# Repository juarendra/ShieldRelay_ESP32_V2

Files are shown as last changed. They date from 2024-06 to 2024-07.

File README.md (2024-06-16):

# ShieldRelay_ESP32
Multiple Relay with ESP32 shield. In board there are 5 Relay and 3 type of Relay, first is 30A Relay Coil, second is 10 A Relay Coil and third is SSR 2A. And there are full extend header of Microcontroller. the power using Stepdown LM2596 with output 5V 3A and Input 5-30VDC. 

## Spesification ShieldRelay_ESP32
- Input Power 5-30VDC and stepdown to 5VDC
- PTC Fuse
- INPUT HEADER
- VCC HEADER
- VCC Selector 3v3 or 5V
- ESP32 WROON on BOARD
- Pin Header GPIO with Servo Formated
- 1 x 30A Relay Coil
- 2 x 10A Relay Coil
- 2 x 2A SSR

# Privew Hardware BASE RPI
<p align="center">
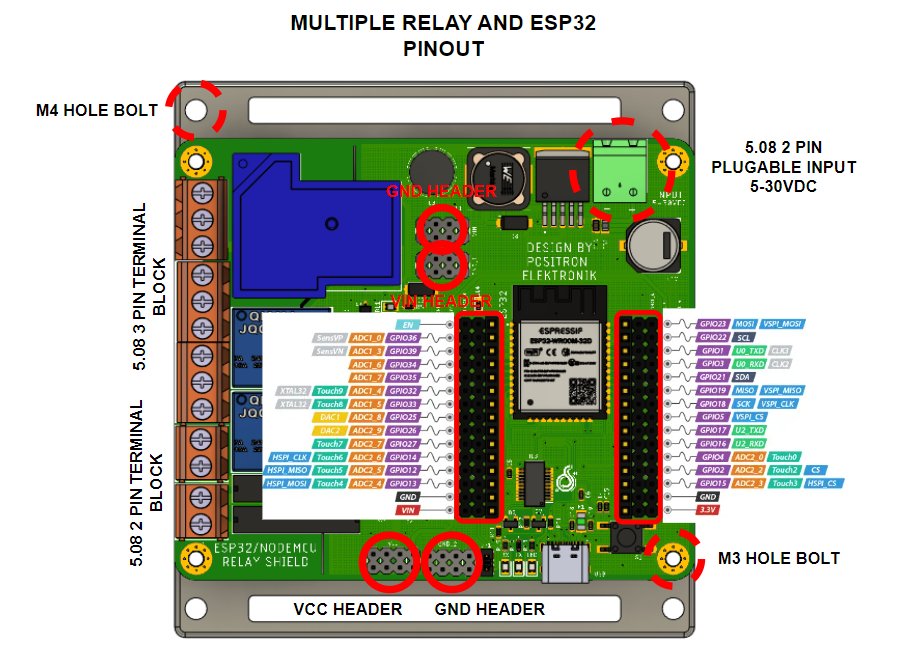
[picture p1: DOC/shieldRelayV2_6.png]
  
</p>

# Privew Hardware BASE RPI
<p align="center">
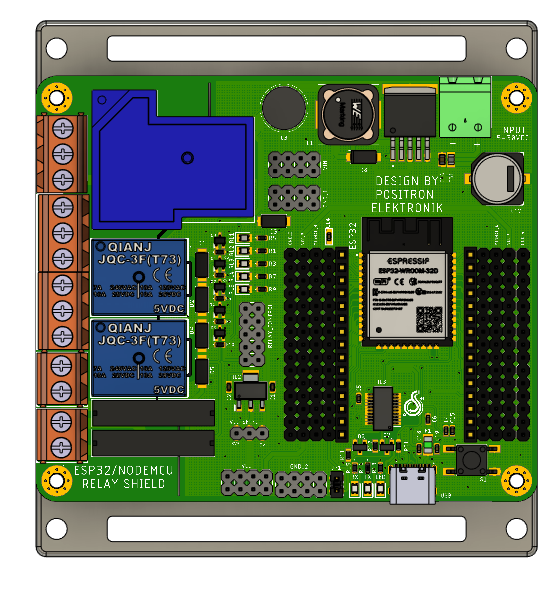
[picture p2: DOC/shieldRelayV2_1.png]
  
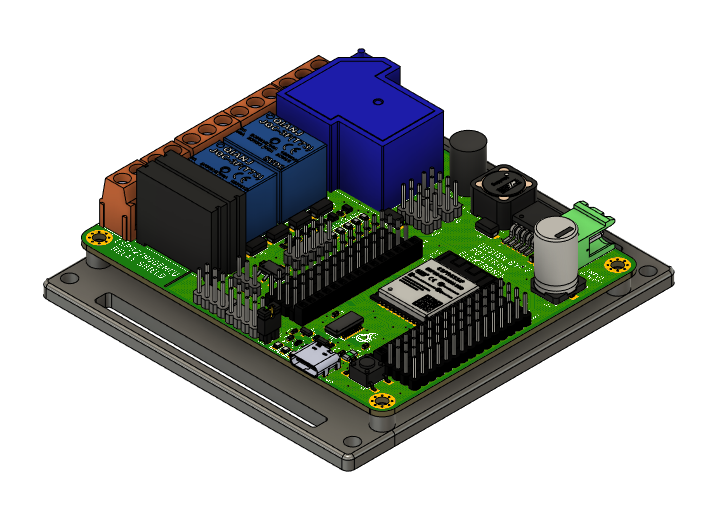
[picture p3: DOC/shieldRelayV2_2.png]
  
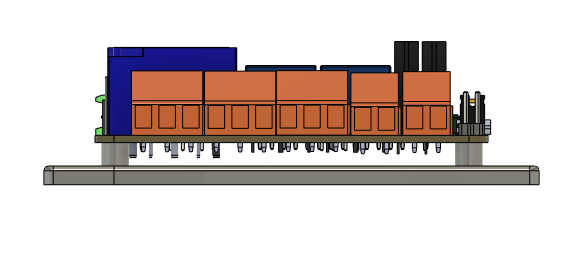
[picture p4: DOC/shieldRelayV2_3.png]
  
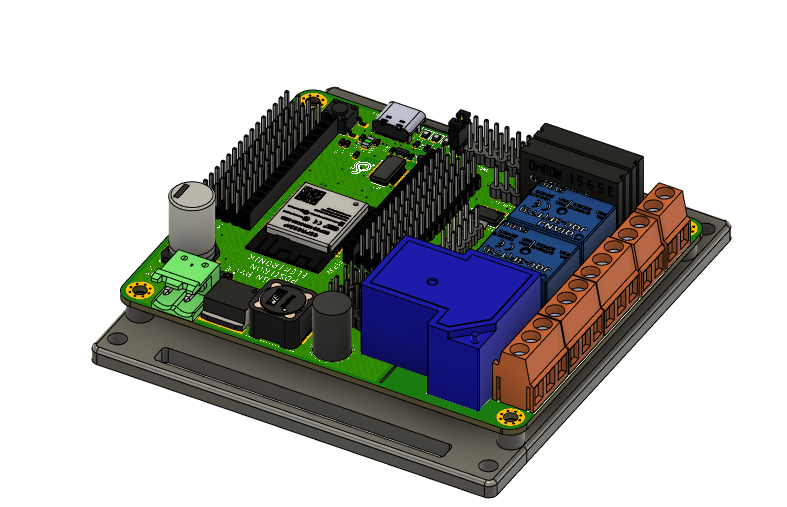
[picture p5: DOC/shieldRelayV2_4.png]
  
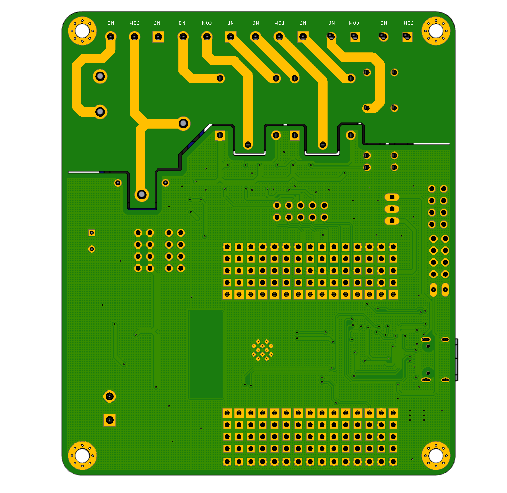
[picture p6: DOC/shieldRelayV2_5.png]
  
</p>

# Documentation 
- [Dimension](https://github.com/juarendra/ShieldRelay_ESP32_V2/blob/main/HARDWARE/dimension_shield_esp32_v2.pdf)
- [BOM](https://github.com/juarendra/ShieldRelay_ESP32_V2/blob/main/DOC/shieldRelayV2.csv)

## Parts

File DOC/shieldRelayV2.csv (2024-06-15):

Qty | Value | Device | Package | Parts | Description | ARROW_PART_NUMBER | ARROW_PRICE-STOCK | AVAILABILITY | CHECK_PRICES | DESCRIPTION | DIGIKEY_PARTNUMBER | DIGIKEY_PRICE-STOCK | ESP32-DEVKITV1 | HEIGHT | MANUFACTURER_NAME | MANUFACTURER_PART_NUMBER | MF | MOUSER_PART_NUMBER | MOUSER_PRICE-STOCK | MP | PACKAGE | POPULARITY | PRICE | PURCHASE-URL | SNAPEDA_LINK | VALUE
1 |  | JP1E | JP1 | JP1 | JUMPER |  |  |  |  |  |  |  |  |  |  |  |  |  |  |  |  | 61
8 |  | PINHD-1X15 | 1X15 | GND_3, GND_4, JP11, JP12, SIGNAL_3, SIGNAL_4, VCC_3, VCC_4 | PIN HEADER |  |  |  |  |  |  |  |  |  |  |  |  |  |  |  |  | 4
1 |  | PINHD-1X3 | 1X03 | VCC_SELECT | PIN HEADER |  |  |  |  |  |  |  |  |  |  |  |  |  |  |  |  | 92
4 |  | PINHD-2X4 | 2X04 | GND_1, GND_2, VCC, VIN | PIN HEADER |  |  |  |  |  |  |  |  |  |  |  |  |  |  |  |  | 47
1 |  | PINHD-2X5 | 2X05 | RELAY_CONTROL | PIN HEADER |  |  |  |  |  |  |  |  |  |  |  |  |  |  |  |  | 35
2 | 0.1uf | KGM15BR71E104KT | CAPC1608X95N | C1, C2 | 0603 25 V X7R 100nF +/-10% |  |  |  |  | 0603 25 V X7R 100nF +/-10% |  |  |  | 0.95mm | Kyocera AVX | KGM15BR71E104KT |  | 581-KGM15BR71E104KT | https://www.mouser.co.uk/ProductDetail/KYOCERA-AVX/KGM15BR71E104KT?qs=Jm2GQyTW%2FbiCo%2Fby4Q068Q%3D%3D
1 | 0ZCJ0010FF2E | 0ZCJ0010FF2E | FUSC3216X75N | F1 | Resettable Fuses - PPTC Fuse |  |  |  |  | Resettable Fuses - PPTC Fuse |  |  |  | 0.75mm | BelFuse | 0ZCJ0010FF2E |  | 530-0ZCJ0010FF2E | https://www.mouser.co.uk/ProductDetail/Bel-Fuse/0ZCJ0010FF2E?qs=SRYZG9HaIQ2ZPdy0ahZ08g%3D%3D
5 | 100nf | 885012206071 | CAPC1608X87N | C5, C6, C15, C18, C19 | Wurth Elektronik 0603 WCAP-CSGP 100nF Ceramic Multilayer Capacitor, 25 V dc, +125C, X7R Dielectric, +/-10% |  |  |  |  | Wurth Elektronik 0603 WCAP-CSGP 100nF Ceramic Multilayer Capacitor, 25 V dc, +125C, X7R Dielectric, +/-10% | 732-7989-1-ND | https://www.digikey.com/product-detail/en/w%C3%BCrth-elektronik/885012206071/732-7989-1-ND/5454616 |  | 0.87mm | Wurth Elektronik | 885012206071 |  | 710-885012206071 | https://www.mouser.co.uk/ProductDetail/Wurth-Elektronik/885012206071?qs=0KOYDY2FL2%2FEBQkuHgvarg%3D%3D |  |  |  |  |  |  | 100nf
3 | 10k | ESR03EZPJ103 | RESC1608X55N | R11, R12, R51 | Thick Film Resistors - SMD 0603 10Kohm 5% Anti Surge AEC-Q200 |  |  |  |  | Thick Film Resistors - SMD 0603 10Kohm 5% Anti Surge AEC-Q200 | RHM10KDCT-ND | https://www.digikey.com/product-detail/en/rohm-semiconductor/ESR03EZPJ103/RHM10KDCT-ND/1762925 |  | 0.55mm | ROHM Semiconductor | ESR03EZPJ103 |  | 755-ESR03EZPJ103 | https://www.mouser.com/Search/Refine.aspx?Keyword=755-ESR03EZPJ103 |  |  |  |  |  |  | 10k
1 | 10nf | 885012206089 | CAPC1608X87N | C4 | Wurth Elektronik 0603 WCAP-CSGP 10nF Ceramic Multilayer Capacitor, 50 V dc, +125C, X7R Dielectric, +/-10% |  |  |  |  | Wurth Elektronik 0603 WCAP-CSGP 10nF Ceramic Multilayer Capacitor, 50 V dc, +125C, X7R Dielectric, +/-10% | 732-8007-1-ND | https://www.digikey.com/product-detail/en/w%C3%BCrth-elektronik/885012206089/732-8007-1-ND/5454634 |  | 0.87mm | Wurth Elektronik | 885012206089 |  | 710-885012206089 | https://www.mouser.co.uk/ProductDetail/Wurth-Elektronik/885012206089?qs=0KOYDY2FL28GvSbKh319Tw%3D%3D |  |  |  |  |  |  | 10nf
5 | 150080SS75000 | 150080SS75000 | LEDC2012X80N | RL1, RL2, RL3, RL4, RL5 | Wurth Elektronik 150080SS75000, WL-SMCW Series Red LED, 630 nm, 2012 (0805) Clear, Rectangle Lens SMD Package |  |  |  |  | Wurth Elektronik 150080SS75000, WL-SMCW Series Red LED, 630 nm, 2012 (0805) Clear, Rectangle Lens SMD Package | 732-4985-1-ND | https://www.digikey.com/product-detail/en/w%C3%BCrth-elektronik/150080SS75000/732-4985-1-ND/4489919 |  | 0.8mm | Wurth Elektronik | 150080SS75000 |  | 710-150080SS75000 | https://www.mouser.co.uk/ProductDetail/Wurth-Elektronik/150080SS75000?qs=LlUlMxKIyB2zzpiaOzrUdw%3D%3D
2 | 1716080000 | 1716080000 | 1716080000 | RELAY4, RELAY5 | Printed circuit board terminals, 5.08 mm, Number of poles: 2, 90, Solder pin length: 3.5 mm, tinned, orange, Clamping yoke connection, Clamping range, max. [rated connection]: 2.5 mm, Box |  |  |  |  | Printed circuit board terminals, 5.08 mm, Number of poles: 2, 90, Solder pin length: 3.5 mm, tinned, orange, Clamping yoke connection, Clamping range, max. [rated connection]: 2.5 mm, Box |  |  |  | 13.8mm | Weidmuller | 1716080000 |  | 470-1716080000 | https://www.mouser.co.uk/ProductDetail/Weidmuller/1716080000?qs=BTG2th8YmhQnu8ZhPH6LgQ%3D%3D
3 | 1716090000 | 1716090000 | SHDR3W95P0X508_1X3_1524X1000X1 | RELAY1, RELAY2, RELAY3 | Printed circuit board terminals, 5.08 mm, Number of poles: 3, 90, Solder pin length: 3.5 mm, tinned, orange, Clamping yoke connection, Clamping range, max. [rated connection]: 2.5 mm, Box |  |  |  |  | Printed circuit board terminals, 5.08 mm, Number of poles: 3, 90, Solder pin length: 3.5 mm, tinned, orange, Clamping yoke connection, Clamping range, max. [rated connection]: 2.5 mm, Box |  |  |  | 13.8mm | Weidmuller | 1716090000 |  | 470-1716090000 | https://www.mouser.co.uk/ProductDetail/Weidmuller/1716090000?qs=BTG2th8YmhRwtiTHzuCKAQ%3D%3D
1 | 1759017 | 1759017 | SHDRRA2W103P0X508_1X2_1016X120 | INPUT | PCB header, nominal cross section: 2.5 mm?, color: green, nominal current: 12 A, rated voltage (III/2): 320 V, contact surface: Tin, type of contact: Male connector, Number of potentials: 2, Number of rows: 1, Number of positions per row: 2, number of connections: 2, product range: MSTB 2,5/..-G, pitch: 5.08 mm, mounting: Wave soldering, pin layout: Linear pinning, solder pin [P]: 3.5 mm, Stecksystem: CLASSIC COMBICON, Locking: without, type of packaging: packed in cardboard |  |  |  |  | PCB header, nominal cross section: 2.5 mm?, color: green, nominal current: 12 A, rated voltage (III/2): 320 V, contact surface: Tin, type of contact: Male connector, Number of potentials: 2, Number of rows: 1, Number of positions per row: 2, number of connections: 2, product range: MSTB 2,5/..-G, pitch: 5.08 mm, mounting: Wave soldering, pin layout: Linear pinning, solder pin [P]: 3.5 mm, Stecksystem: CLASSIC COMBICON, Locking: without, type of packaging: packed in cardboard |  |  |  | 8.72mm | Phoenix Contact | 1759017 |  | 651-1759017 | https://www.mouser.co.uk/ProductDetail/Phoenix-Contact/1759017?qs=BYlwlsDsB%2FoOYIHqYLxOcg%3D%3D
10 | 1k | ERA-3AED102V | ERA3AEB101V | R1, R2, R3, R4, R5, R6, R7, R8, R9, R10 | Thin Film Resistors - SMD 0603 1000ohms 25ppm 0.5% AEC-Q200 |  |  |  |  | Thin Film Resistors - SMD 0603 1000ohms 25ppm 0.5% AEC-Q200 |  |  |  | 0.55mm | Panasonic | ERA-3AED102V |  | 667-ERA-3AED102V | https://www.mouser.co.uk/ProductDetail/Panasonic/ERA-3AED102V?qs=yocZuyCaXdNrh6oeFjCchg%3D%3D
1 | 1uF | CAP_CERAMIC0603 | 0603 | C14 | Ceramic Capacitors
1 | 2.2uf | KAF21KR71H225KU | CAPC2012X140N | C16 | Multilayer Ceramic Capacitors MLCC - SMD/SMT 50V 2.2uF X7R 0805 10% AEC-Q200 FLEXITERM |  |  |  |  | Multilayer Ceramic Capacitors MLCC - SMD/SMT 50V 2.2uF X7R 0805 10% AEC-Q200 FLEXITERM |  |  |  | 1.4mm | Kyocera AVX | KAF21KR71H225KU |  | 581-KAF21KR71H225KU | https://www.mouser.co.uk/ProductDetail/KYOCERA-AVX/KAF21KR71H225KU?qs=Jm2GQyTW%2FbjwwNTLmtUMeQ%3D%3D
1 | 220uf 25V | MAL203836221E3 | CAPPRD350W60D850H1250 | C3 | VISHAY - MAL203836221E3 - CAP, 220F, 25V, 20% |  |  |  |  | VISHAY - MAL203836221E3 - CAP, 220F, 25V, 20% |  |  |  | 12.5mm | Vishay | MAL203836221E3 |  | 594-MAL203836221E3 | https://www.mouser.co.uk/ProductDetail/Vishay-BC-Components/MAL203836221E3?qs=G99oyVYclWUIwcN6B3qC5w%3D%3D
3 | 330 | ERJ-H3EF3300V | ERJH3 | R13, R14, R15 | Power Rating 0.125W,Resistance 330 Ohm,LxW(EIA) 1.6 x 0.8 (EIA:0603) mm |  |  |  |  | Power Rating 0.125W,Resistance 330 Ohm,LxW(EIA) 1.6 x 0.8 (EIA:0603) mm |  |  |  | mm | Panasonic | ERJ-H3EF3300V |  | 667-ERJ-H3EF3300V | https://www.mouser.co.uk/ProductDetail/Panasonic/ERJ-H3EF3300V?qs=eP2BKZSCXI61roRLPi8W7w%3D%3D |  |  |  |  |  |  | 330
1 | 33uh 12x12 | 744770133 | WE-PD_1260/1245/1280/121054 | L1 | Wurth WE-PD Series Shielded Wire-wound SMD Inductor with a Ferrite Core, 33 uH +/-20% 3.6A Idc |  |  |  |  | Wurth WE-PD Series Shielded Wire-wound SMD Inductor with a Ferrite Core, 33 uH +/-20% 3.6A Idc |  |  |  | mm | Wurth Elektronik | 744770133 |  | 710-744770133 | https://www.mouser.co.uk/ProductDetail/Wurth-Elektronik/744770133?qs=E%2F%2FhvbtCqpPKkGJl8TxFXw%3D%3D
4 | 3MM_HOLE | 3MM_HOLE | 3MM_HOLE | H1, H2, H3, H4 | Cool looking 3mm hole with ground connection
1 | 680uf | EEH-ZU1V681UP | EEHZS1H221P | C17 | Conductive Polymer Hybrid Aluminum Electrolytic Capacitor |  |  |  |  | Conductive Polymer Hybrid Aluminum Electrolytic Capacitor |  |  |  | 10.5mm | Panasonic | EEH-ZU1V681UP |  | 667-EEH-ZU1V681UP | https://www.mouser.co.uk/ProductDetail/Panasonic/EEH-ZU1V681UP?qs=HoCaDK9Nz5elLexP3akqig%3D%3D
1 | B340A-13-F | B340A-13-F | DIOM5226X240N | D8 | Schottky Diode 3A 40V 0.5Vf SMA Diodes Inc B340A-13-F, SMT Schottky Diode, 40V 3A, 2-Pin DO-214AC |  |  |  |  | Schottky Diode 3A 40V 0.5Vf SMA Diodes Inc B340A-13-F, SMT Schottky Diode, 40V 3A, 2-Pin DO-214AC |  |  |  | 2.4mm | Diodes Incorporated | B340A-13-F |  | 621-B340A-F | https://www.mouser.co.uk/ProductDetail/Diodes-Incorporated/B340A-13-F?qs=aLaTXeBcTP9fj%2FYKVo6Q1A%3D%3D
1 | BLM21PG221SN1D | BLM21PG221SN1D | BEADC2012X105N | FB1 | Murata Ferrite Bead (Chip Ferrite Bead), 2 x 1.25 x 0.85mm |  |  |  |  | Murata Ferrite Bead (Chip Ferrite Bead), 2 x 1.25 x 0.85mm |  |  |  | 1.05mm | Murata Electronics | BLM21PG221SN1D |  | 81-BLM21P221SG | https://www.mouser.co.uk/ProductDetail/Murata-Electronics/BLM21PG221SN1D?qs=N%2FLoXOA9PTJ4i6RHFrsqmw%3D%3D
1 | ESP32-WROOM-32D | ESP32-WROOM-32D | MODULE_ESP32-WROOM-32D | ESP32 | Bluetooth, WiFi 802.11b/g/n, Bluetooth v4.2 + EDR, Class 1, 2 and 3 Transceiver Module 2.4GHz ~ 2.5GHz Integrated, Trace Surface Mount Check availability |  |  | In Stock |  | Bluetooth, WiFi 802.11b/g/n, Bluetooth v4.2 +EDR, Class 1, 2 and 3 Transceiver Module 2.4GHz ~ 2.5GHz Integrated |  |  |  |  |  |  | Espressif Systems |  |  | ESP32-WROOM-32D | Module Espressif Systems |  | None | https://pricing.snapeda.com/search/part/ESP32-WROOM-32D/?ref=eda
1 | ESP32DEVKITV1 | ESP32DEVKITV1 | ESP32-DEVKITV1 | BOARD | https://github.com/shridattdudhat
5 | FM4004-W | FM4004-W | DIONM5025X231N | D1, D2, D3, D4, D5 | Rectifiers 1N4004 1A 400V |  |  |  |  | Rectifiers 1N4004 1A 400V |  |  |  | 2.31mm | Rectron | FM4004-W |  | 583-FM4004 | https://www.mouser.co.uk/ProductDetail/Rectron/FM4004-W?qs=Iw9Ubr57Px3IHNH1bE4l9w%3D%3D
1 | FSM2JSMAATR | FSM2JSMAATR | FSM2J_1 | S1 | Tactile switch,SMT,SPST,raised white act |  |  |  |  | Tactile switch,SMT,SPST,raised white act |  |  |  | mm | TE Connectivity | FSM2JSMAATR |  | 506-FSM2JSMAATR | https://www.mouser.co.uk/ProductDetail/TE-Connectivity-Alcoswitch/FSM2JSMAATR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
1 | FT231XS-R | FT231XS-R | SOP64P599X175-20N | IC3 | FTDI Chip FT231XS-R, Interface RS232, RS422, RS485, SIE, UART 3MBd, 5 V, 20-pin, SSOP |  |  |  |  | FTDI Chip FT231XS-R, Interface RS232, RS422, RS485, SIE, UART 3MBd, 5 V, 20-pin, SSOP |  |  |  | 1.753mm | FTDI Chip | FT231XS-R |  | 895-FT231XS-R | https://www.mouser.co.uk/ProductDetail/FTDI/FT231XS-R?qs=Gp1Yz1mis3WduRPsgrTbtg%3D%3D
2 | G3MB-202PL-DC5 | G3MB-202PL-DC5 | G3MB202PLDC5 | K3, K5 | Solid State Relays - PCB Mount 5VDC/100-240VAC 2A |  |  |  |  | Solid State Relays - PCB Mount 5VDC/100-240VAC 2A |  |  |  | 20.5mm | Omron Electronics | G3MB-202PL-DC5 |  | 653-G3MB-202PL-DC5 | https://www.mouser.co.uk/ProductDetail/Omron-Automation-and-Safety/G3MB-202PL-DC5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
3 | Green | 150080BS75000 | LEDC2012X80N | LED, RX, TX | LED,Wurth Elektronik,150080BS75000 Wurth Elektronik 150080BS75000, WL-SMCW Series Blue LED, 470 nm 2012 (0805) Clear, Rectangle Lens SMD package |  |  |  |  | LED,Wurth Elektronik,150080BS75000 Wurth Elektronik 150080BS75000, WL-SMCW Series Blue LED, 470 nm 2012 (0805) Clear, Rectangle Lens SMD package |  |  |  | 0.8mm | Wurth Elektronik | 150080BS75000 |  | 710-150080BS75000 | https://www.mouser.co.uk/ProductDetail/Wurth-Elektronik/150080BS75000?qs=2kOmHSv6VfT2tBo3UPVqAQ%3D%3D |  |  |  |  |  |  | Green
1 | LM1117MPX-33NOPB | LM1117MPX-33NOPB | SOT230P700X180-4N | IC2 | LDO Voltage Regulators 800-mA 15-V linear voltage regulator 800-mA 15-V linear voltage regulator |  |  |  |  | LDO Voltage Regulators 800-mA 15-V linear voltage regulator 800-mA 15-V linear voltage regulator |  |  |  | 1.8mm | onsemi | LM1117MPX-33NOPB |  | 863-LM1117MPX-33NOPB | https://www.mouser.co.uk/ProductDetail/onsemi/LM1117MPX-33NOPB?qs=DPoM0jnrROUIbzbQHFmeig%3D%3D
1 | LM2596SX-5.0_NOPB | LM2596SX-5.0_NOPB | KTT0005B | IC1 | SIMPLE SWITCHER&#174; 4.5V to 40V, 3A Low Component Count Step-Down Regulator |  |  |  |  | SIMPLE SWITCHER&#174 | 4.5V to 40V, 3A Low Component Count Step-Down Regulator |  |  |  | mm | Texas Instruments | LM2596SX-5.0/NOPB |  | 926-LM2596SX-5.0NOPB | https://www.mouser.co.uk/ProductDetail/Texas-Instruments/LM2596SX-5.0-NOPB?qs=X1J7HmVL2ZGZ5T4VcWdmNw%3D%3D
2 | MMBT3904-TP | MMBT3904-TP | SI2305TP | Q6, Q7 | Bipolar Transistors - BJT 40V |  |  |  |  | Bipolar Transistors - BJT 40V |  |  |  | mm | Micro Commercial Components (MCC) | MMBT3904-TP |  | 833-MMBT3904-TP | https://www.mouser.co.uk/ProductDetail/Micro-Commercial-Components-MCC/MMBT3904-TP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
5 | MMST2222A-7-F | MMST2222A-7-F | SOT65P210X110-3N | Q1, Q2, Q3, Q4, Q5 | Bipolar (BJT) Transistor NPN 40 V 600 mA 300MHz 200 mW Surface Mount SOT-323 |  |  |  |  | Bipolar (BJT) Transistor NPN 40 V 600 mA 300MHz 200 mW Surface Mount SOT-323 |  |  |  | 1.1mm | Diodes Incorporated | MMST2222A-7-F |  | 621-MMST2222A-F | https://www.mouser.co.uk/ProductDetail/Diodes-Incorporated/MMST2222A-7-F?qs=B0AElM0L7fPu4CagNNXsRQ%3D%3D
1 | SLA-05VDC-SL-C | SLA-05VDC-SL-C | SLA05VDCSLC | K1 | Relays General Purpose Non Latching 5VDC SPDT 30A (250VAC) Max Plugin RoHS |  |  |  |  | Relays General Purpose Non Latching 5VDC SPDT 30A (250VAC) Max Plugin RoHS |  |  |  | 20.4mm | Songle Relay | SLA-05VDC-SL-C
2 | SRD-05VDC-SL-C | SRD-05VDC-SL-C | SRD05VDCSLC | K2, K6 | SRD-05VDC-SL-C; RELAY ISO9002 1. MAIN FEATURES Switching capacity available by 10A in spite of small size design for highdensity P.C. board mounting technique. U |  |  |  |  | SRD-05VDC-SL-C | RELAY ISO9002 1. MAIN FEATURES Switching capacity available by 10A in spite of small size design for highdensity P.C. board mounting technique. U |  |  |  | 15.8mm | EAGLE | SRD-05VDC-SL-C
1 | TYPE-C-31-M-12 | TYPE-C-31-M-12 | HRO_TYPE-C-31-M-12 | USB | Check availability |  |  | Not in stock | https://www.snapeda.com/parts/TYPE-C-31-M-12/HRO+Electronics+Co.%252C+Ltd./view-part/?ref=eda | USB Connectors 24 Receptacle 1 8.94*7.3mm RoHS |  |  |  |  |  |  | HRO Electronics Co., Ltd. |  |  | TYPE-C-31-M-12 | Package |  | None |  | https://www.snapeda.com/parts/TYPE-C-31-M-12/HRO+Electronics+Co.%252C+Ltd./view-part/?ref=snap

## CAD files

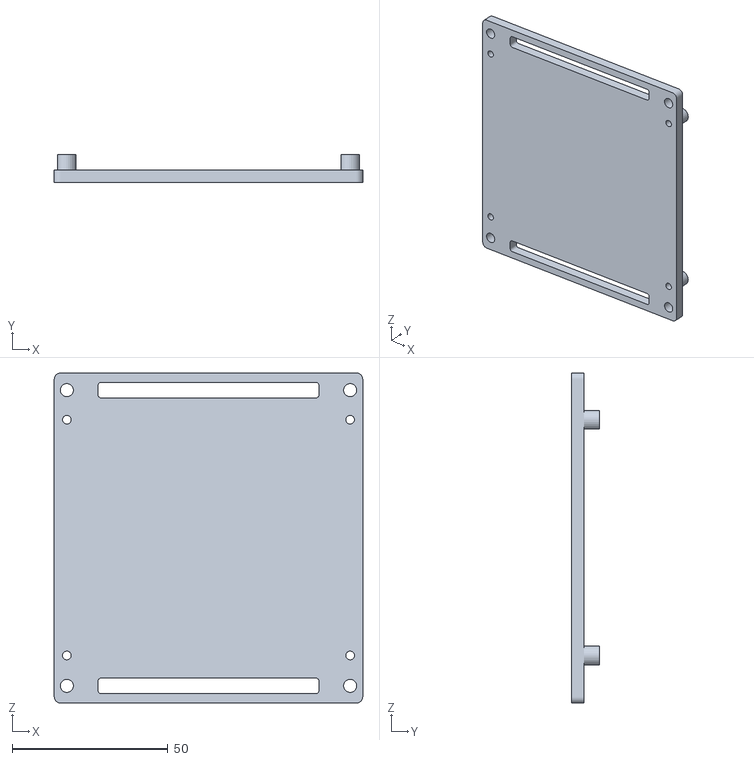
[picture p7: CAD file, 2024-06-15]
HARDWARE/PLATE/shieldRelayPlate.stl
99.1 x 9.00 x 105.9

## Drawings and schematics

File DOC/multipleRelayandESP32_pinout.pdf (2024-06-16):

## MULTIPLE RELAY AND ESP32 PINOUT

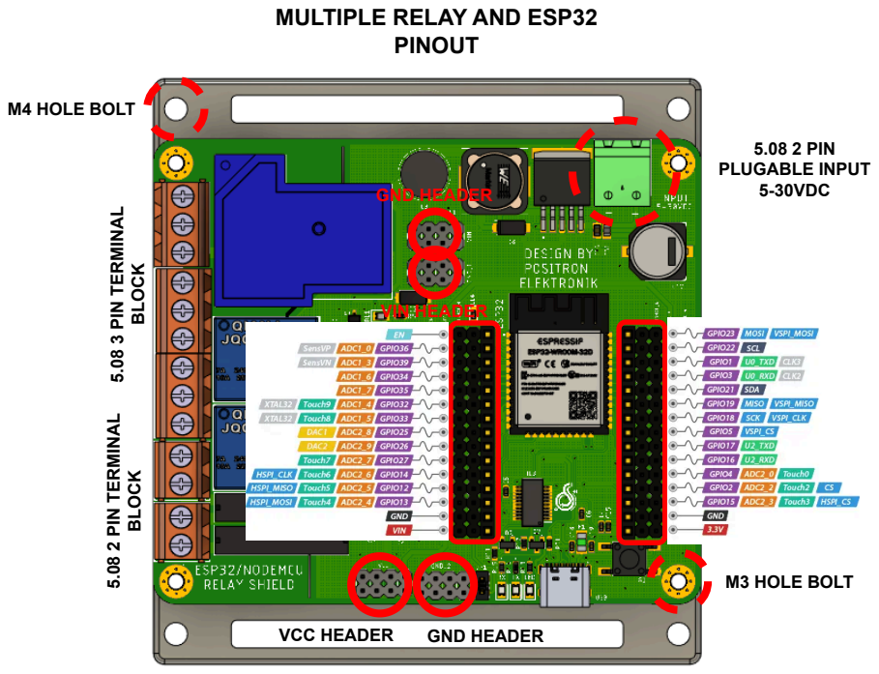
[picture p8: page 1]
5.08 2 PIN PLUGABLE INPUT 5-30VDC; M4 HOLE BOLT; M3 HOLE BOLT; 5.08 3 PIN TERMINAL; BLOCK; 5.08 2 PIN TERMINAL; VCC HEADER; GND HEADER; VIN HEADER

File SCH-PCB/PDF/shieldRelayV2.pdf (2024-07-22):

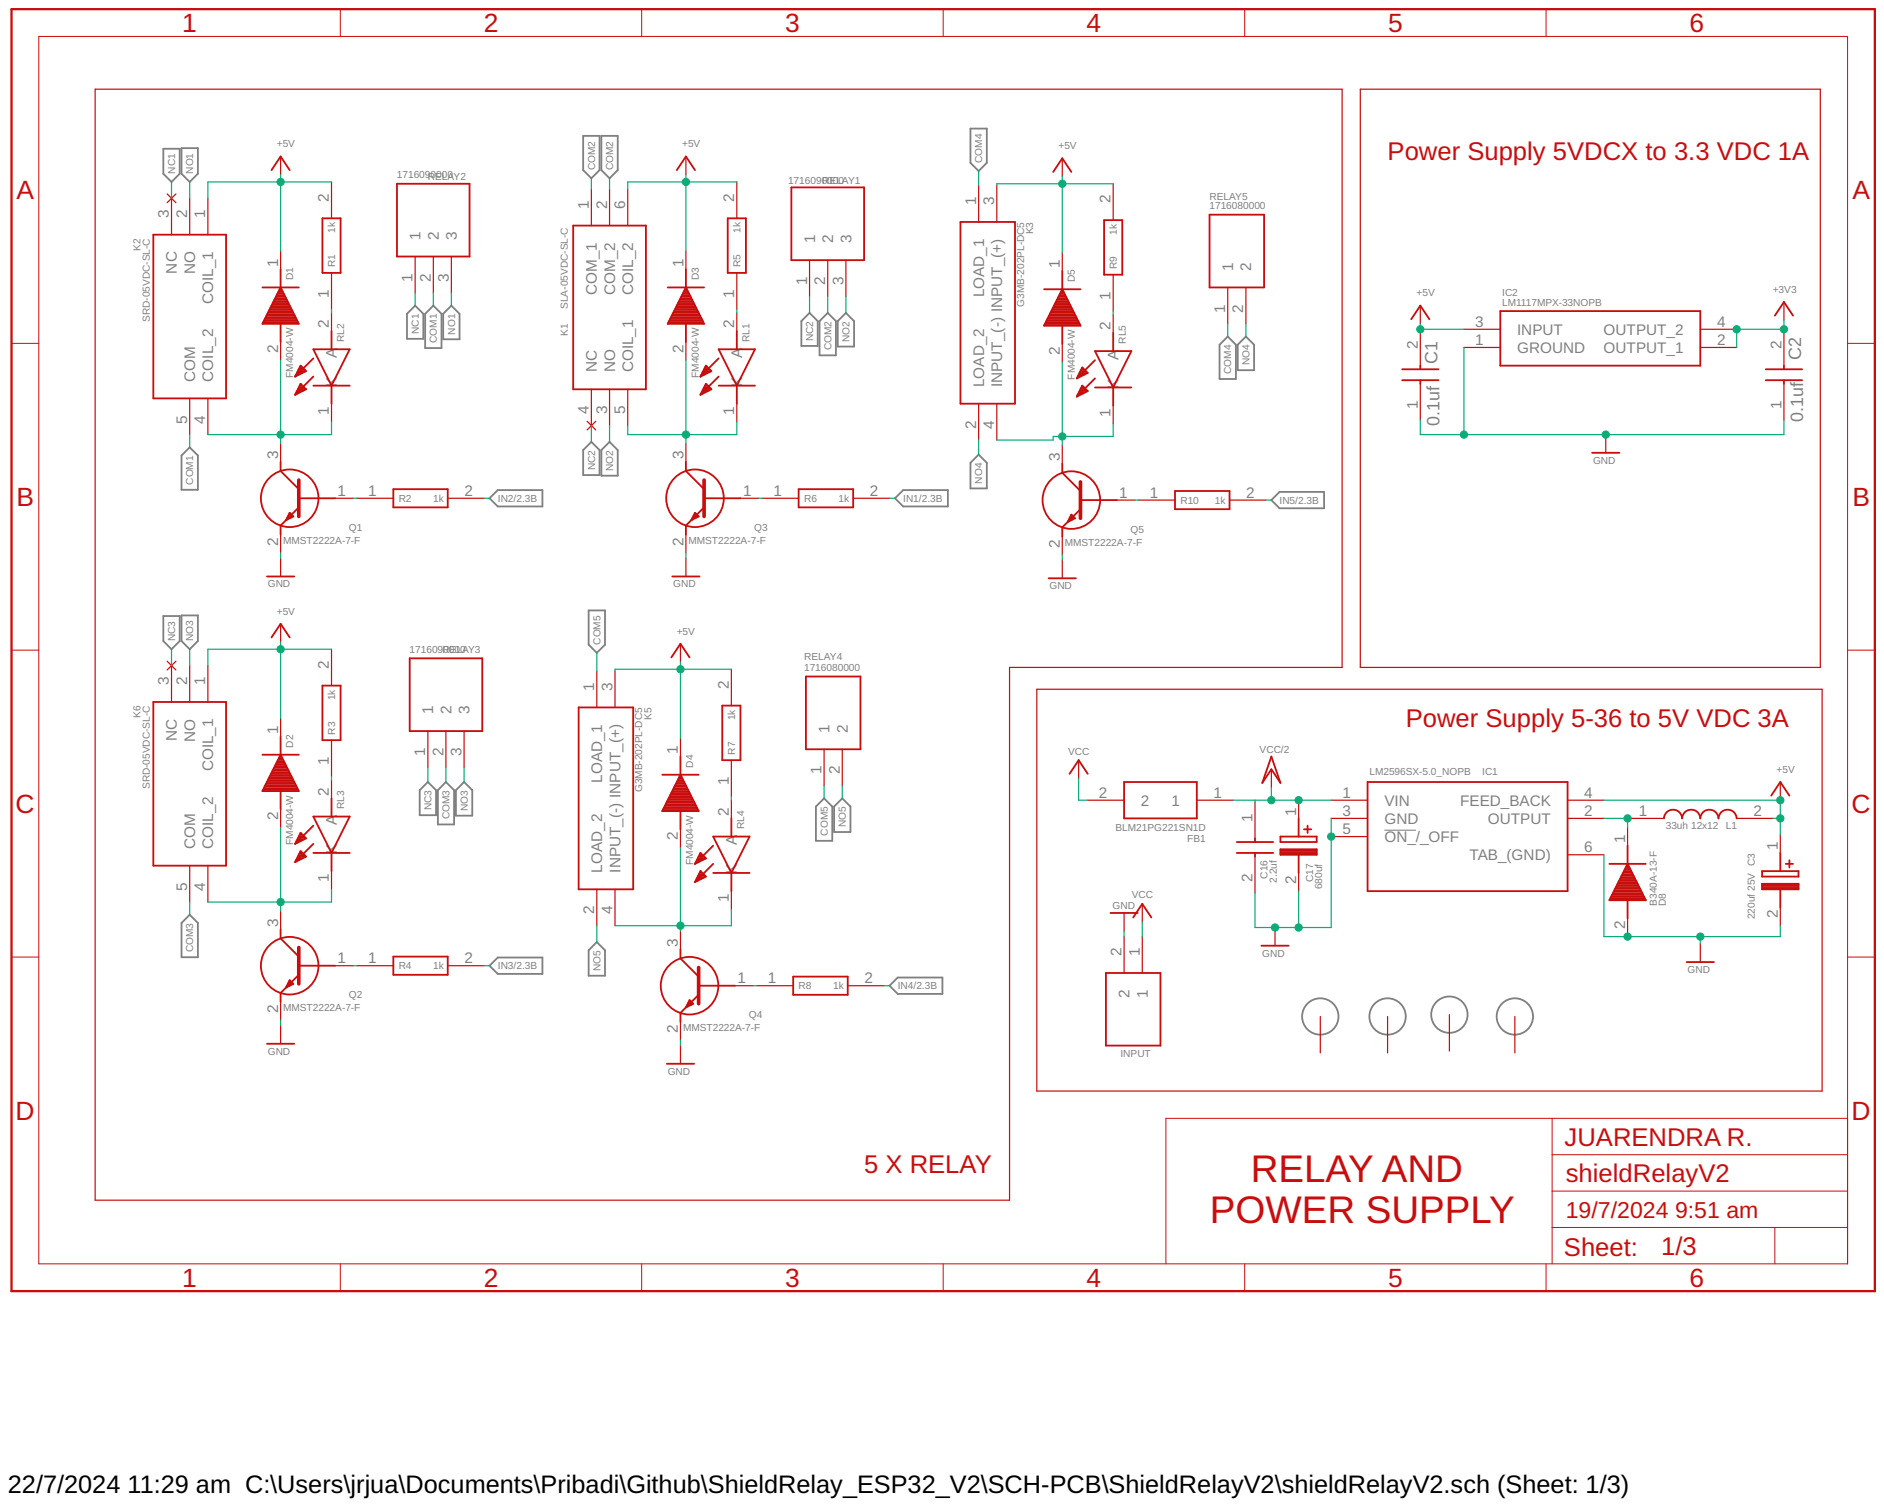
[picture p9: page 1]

Power Supply 5VDCX to 3.3 VDC 1A

NO4 Power Supply 5-36 to 5V VDC 3A

RELAY AND POWER SUPPLY

22/7/2024 11:29 am C:\Users\jrjua\Documents\Pribadi\Github\ShieldRelay_ESP32_V2\SCH-PCB\ShieldRelayV2\shieldRelayV2.sch (Sheet: 1/3)

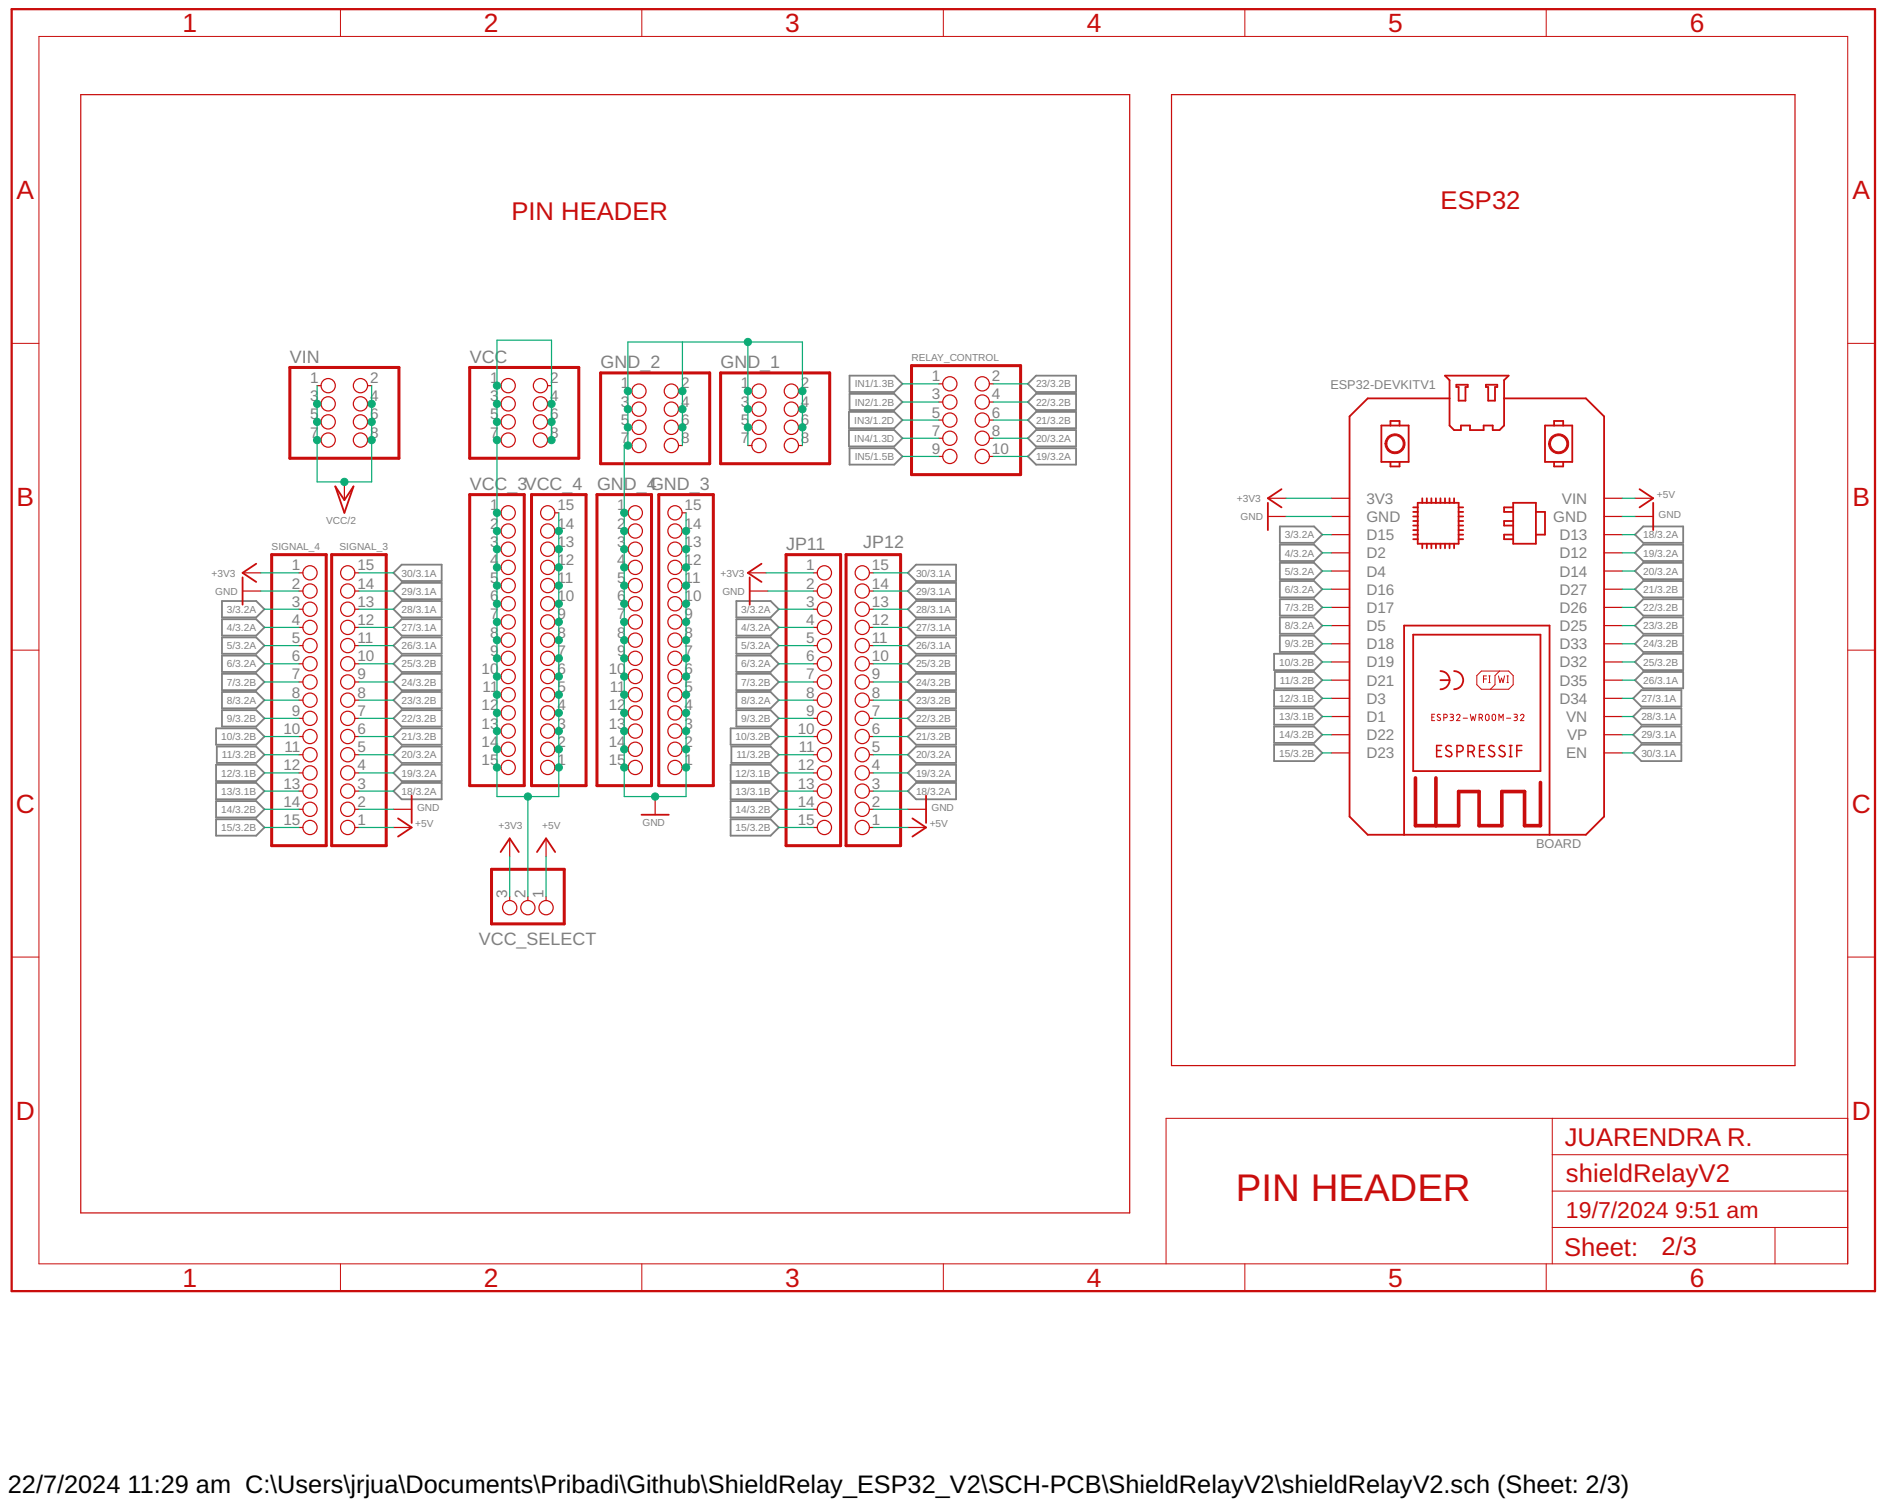
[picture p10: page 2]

22/7/2024 11:29 am C:\Users\jrjua\Documents\Pribadi\Github\ShieldRelay_ESP32_V2\SCH-PCB\ShieldRelayV2\shieldRelayV2.sch (Sheet: 2/3)

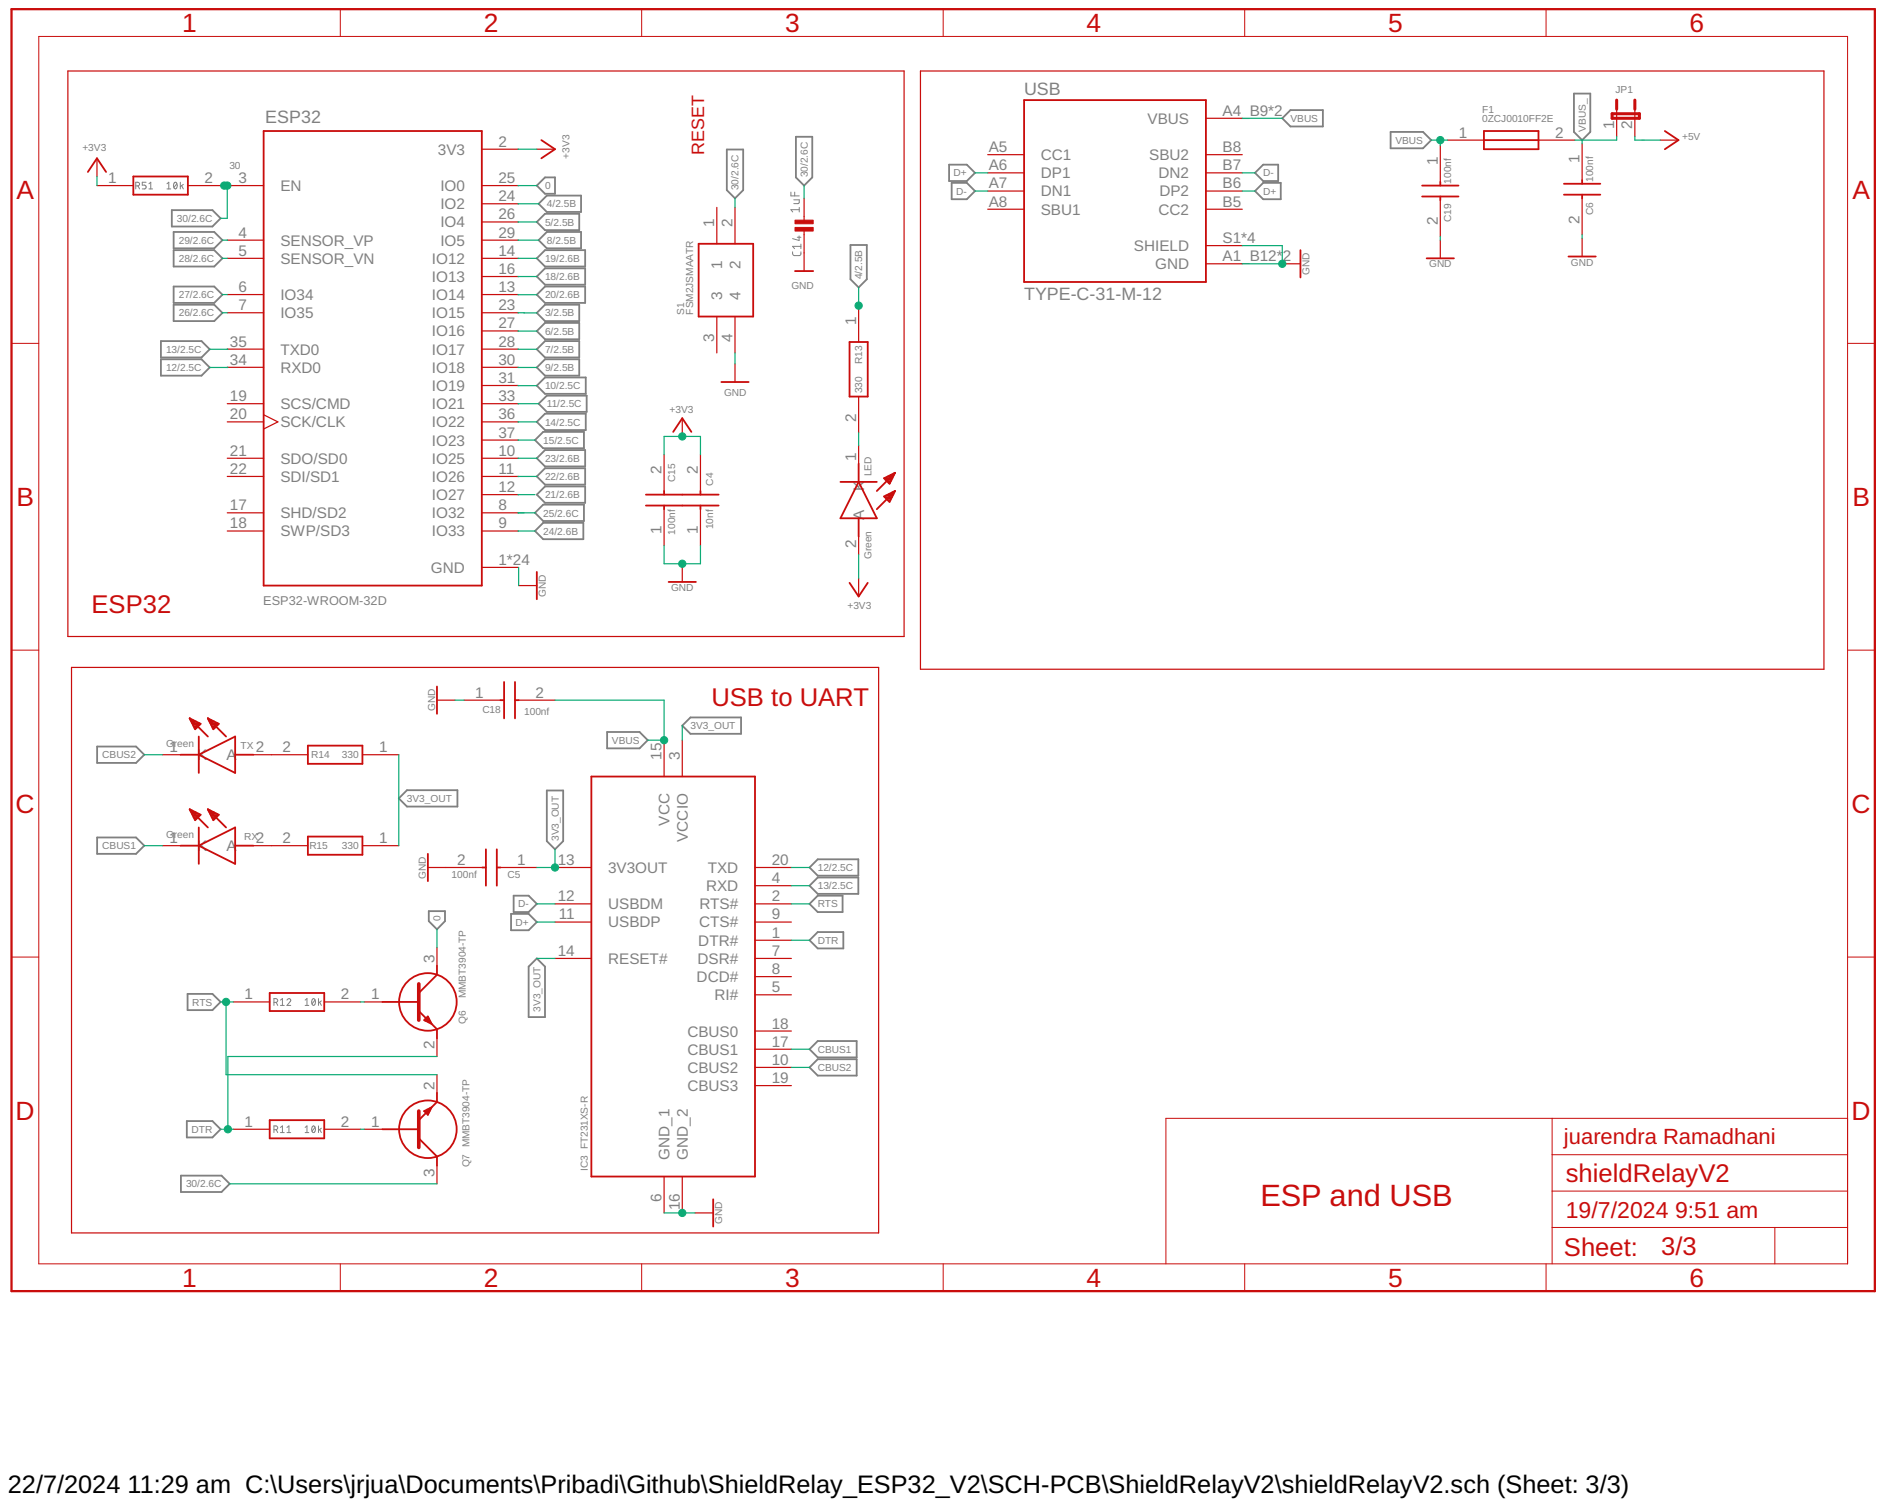
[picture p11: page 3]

22/7/2024 11:29 am C:\Users\jrjua\Documents\Pribadi\Github\ShieldRelay_ESP32_V2\SCH-PCB\ShieldRelayV2\shieldRelayV2.sch (Sheet: 3/3)

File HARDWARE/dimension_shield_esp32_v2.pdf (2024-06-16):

105.95 ⁹⁹.06 | Ø4.2
84.07 | 99.06 Ø3.2 2. SIDE VIEW | 6. ISOMETRIC VIEW ³. SIDE VIEW ⁴. SIDE VIEW | 5. SIDE VIEW 5 4

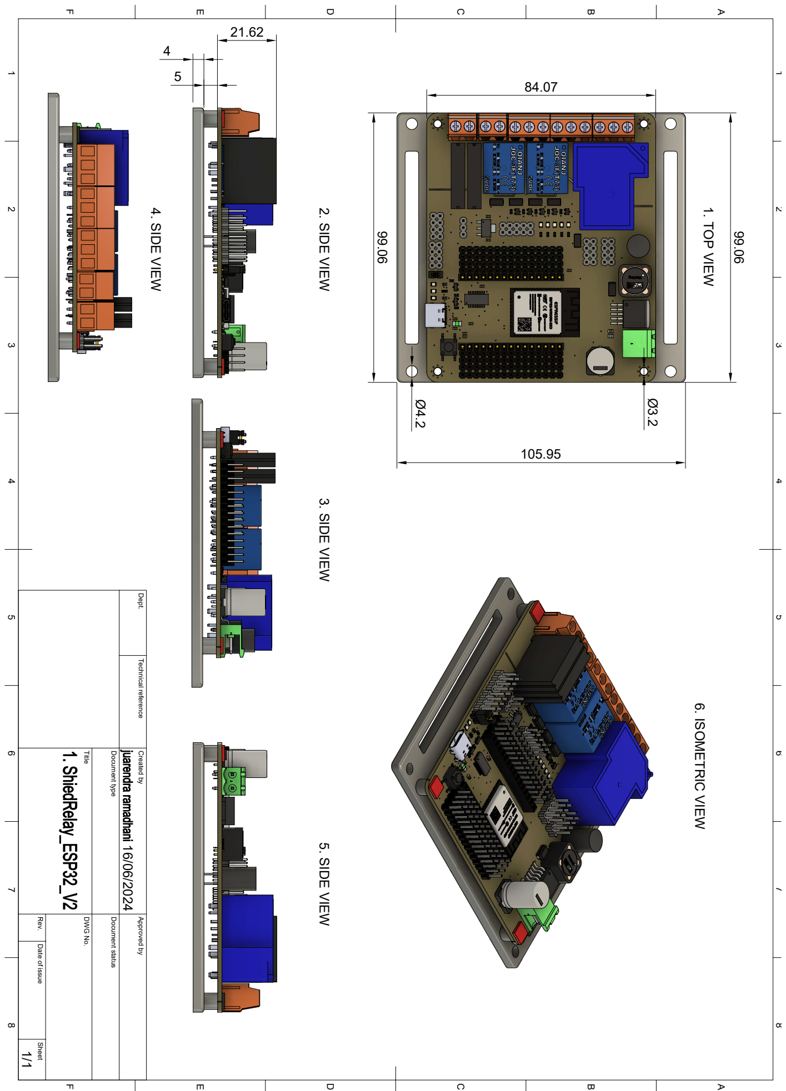
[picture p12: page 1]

1 A 2 3 4 5 6 7 8 1 2 3 4 5 6 7 8 FEDCB FEDCBA Dept. Technical reference Created by Approved by Title DWG No. Document type Document status Rev. Date of issue Sheet 16/06/2024 1/1 1. TOP VIEW

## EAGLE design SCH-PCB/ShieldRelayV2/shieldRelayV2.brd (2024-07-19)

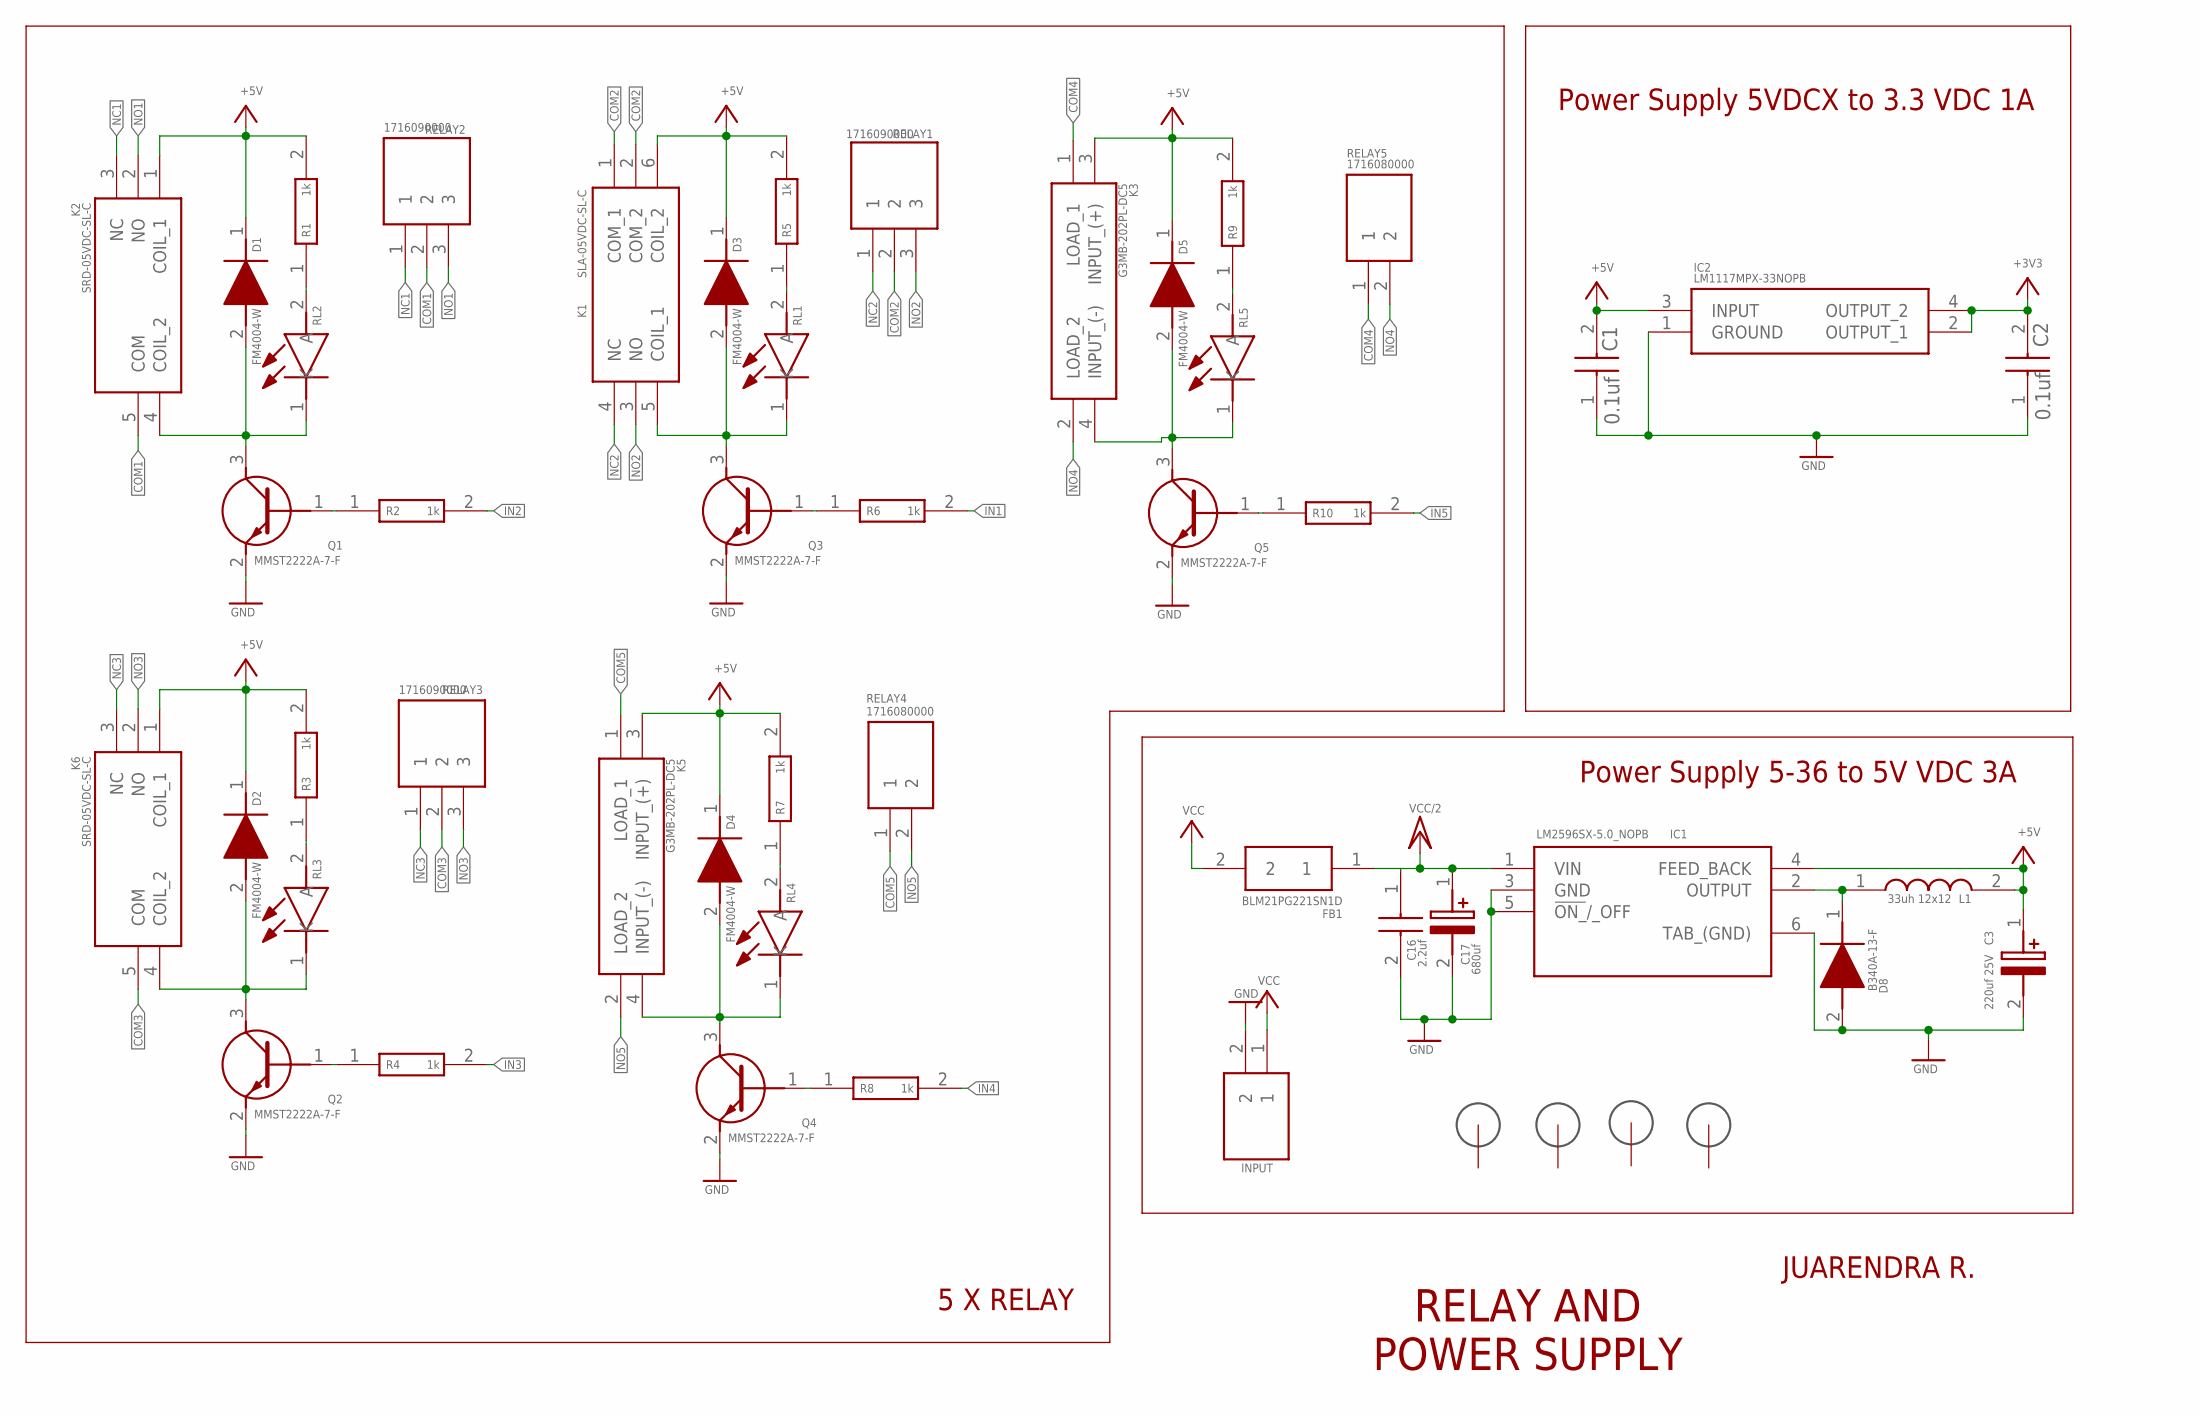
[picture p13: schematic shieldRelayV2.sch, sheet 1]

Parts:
C1, C2: 0.1uf; CAPC1608X95N
C3: 220uf 25V; CAPPRD350W60D850H1250
C16: 2.2uf; CAPC2012X140N
C17: 680uf; EEHZS1H221P
D1, D2, D3, D4, D5: FM4004-W; DIONM5025X231N
D8: B340A-13-F; DIOM5226X240N
FB1: BLM21PG221SN1D; BEADC2012X105N
H1, H2, H3, H4: 3MM_HOLE
IC1: LM2596SX-5.0_NOPB; KTT0005B
IC2: LM1117MPX-33NOPB; SOT230P700X180-4N
INPUT: 1759017; SHDRRA2W103P0X508_1X2_1016X120
K1: SLA-05VDC-SL-C; SLA05VDCSLC
K2, K6: SRD-05VDC-SL-C; SRD05VDCSLC
K3, K5: G3MB-202PL-DC5; G3MB202PLDC5
L1: 33uh 12x12; WE-PD_1260/1245/1280/121054
Q1, Q2, Q3, Q4, Q5: MMST2222A-7-F; SOT65P210X110-3N
R1, R2, R3, R4, R5, R6, R7, R8, R9, R10: 1k; ERA3AEB101V
RELAY1, RELAY2, RELAY3: 1716090000; SHDR3W95P0X508_1X3_1524X1000X1
RELAY4, RELAY5: 1716080000
RL1, RL2, RL3, RL4, RL5: 150080SS75000; LEDC2012X80N

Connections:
+3V3: C2.2, IC2.2 (OUTPUT_1), IC2.4 (OUTPUT_2); also elsewhere on the board
+5V: C1.2, C3.1 (+), D1.1 (K), D2.1 (K), D3.1 (K), D4.1 (K), D5.1 (K), IC1.4 (FEED_BACK), IC2.3 (INPUT), K1.6 (COIL_2), K2.1 (COIL_1), K3.3 (INPUT_(+)), K5.3 (INPUT_(+)), K6.1 (COIL_1), L1.2, R1.2, R3.2, R5.2, R7.2, R9.2; also elsewhere on the board
COM1: K2.5 (COM), RELAY2.2
COM2: K1.1 (COM_1), K1.2 (COM_2), RELAY1.2
COM3: K6.5 (COM), RELAY3.2
COM4: K3.1 (LOAD_1), RELAY5.1
COM5: K5.1 (LOAD_1), RELAY4.1
GND: C1.1, C2.1, C3.2 (-), C16.2, C17.2 (-), D8.2 (A), IC1.3 (GND), IC1.5 (!ON_!/_OFF), IC1.6 (TAB_(GND)), IC2.1 (GROUND), INPUT.2, Q1.2 (E), Q2.2 (E), Q3.2 (E), Q4.2 (E), Q5.2 (E); also elsewhere on the board
IN1: R6.2; also elsewhere on the board
IN2: R2.2; also elsewhere on the board
IN3: R4.2; also elsewhere on the board
IN4: R8.2; also elsewhere on the board
IN5: R10.2; also elsewhere on the board
unnamed: R3.1, RL3.2 (A)
unnamed: R1.1, RL2.2 (A)
unnamed: D1.2 (A), K2.4 (COIL_2), Q1.3 (C), RL2.1 (K)
unnamed: Q2.1 (B), R4.1
unnamed: D2.2 (A), K6.4 (COIL_2), Q2.3 (C), RL3.1 (K)
unnamed: R5.1, RL1.2 (A)
unnamed: D3.2 (A), K1.5 (COIL_1), Q3.3 (C), RL1.1 (K)
unnamed: Q1.1 (B), R2.1
unnamed: R7.1, RL4.2 (A)
unnamed: D4.2 (A), K5.4 (INPUT_(-)), Q4.3 (C), RL4.1 (K)
unnamed: Q4.1 (B), R8.1
unnamed: R9.1, RL5.2 (A)
unnamed: D5.2 (A), K3.4 (INPUT_(-)), Q5.3 (C), RL5.1 (K)
unnamed: Q3.1 (B), R6.1
unnamed: D8.1 (K), IC1.2 (OUTPUT), L1.1
unnamed: Q5.1 (B), R10.1
NC1: K2.3 (NC), RELAY2.1
NC2: K1.4 (NC), RELAY1.1
NC3: K6.3 (NC), RELAY3.1
NO1: K2.2 (NO), RELAY2.3
NO2: K1.3 (NO), RELAY1.3
NO3: K6.2 (NO), RELAY3.3
NO4: K3.2 (LOAD_2), RELAY5.2
NO5: K5.2 (LOAD_2), RELAY4.2
VCC: FB1.2, INPUT.1
VCC/2: C16.1, C17.1 (+), FB1.1, IC1.1 (VIN); also elsewhere on the board

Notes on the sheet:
Power Supply 5-36 to 5V VDC 3A
5 X RELAY
Power Supply 5VDCX to 3.3 VDC 1A
RELAY AND POWER SUPPLY
JUARENDRA R.

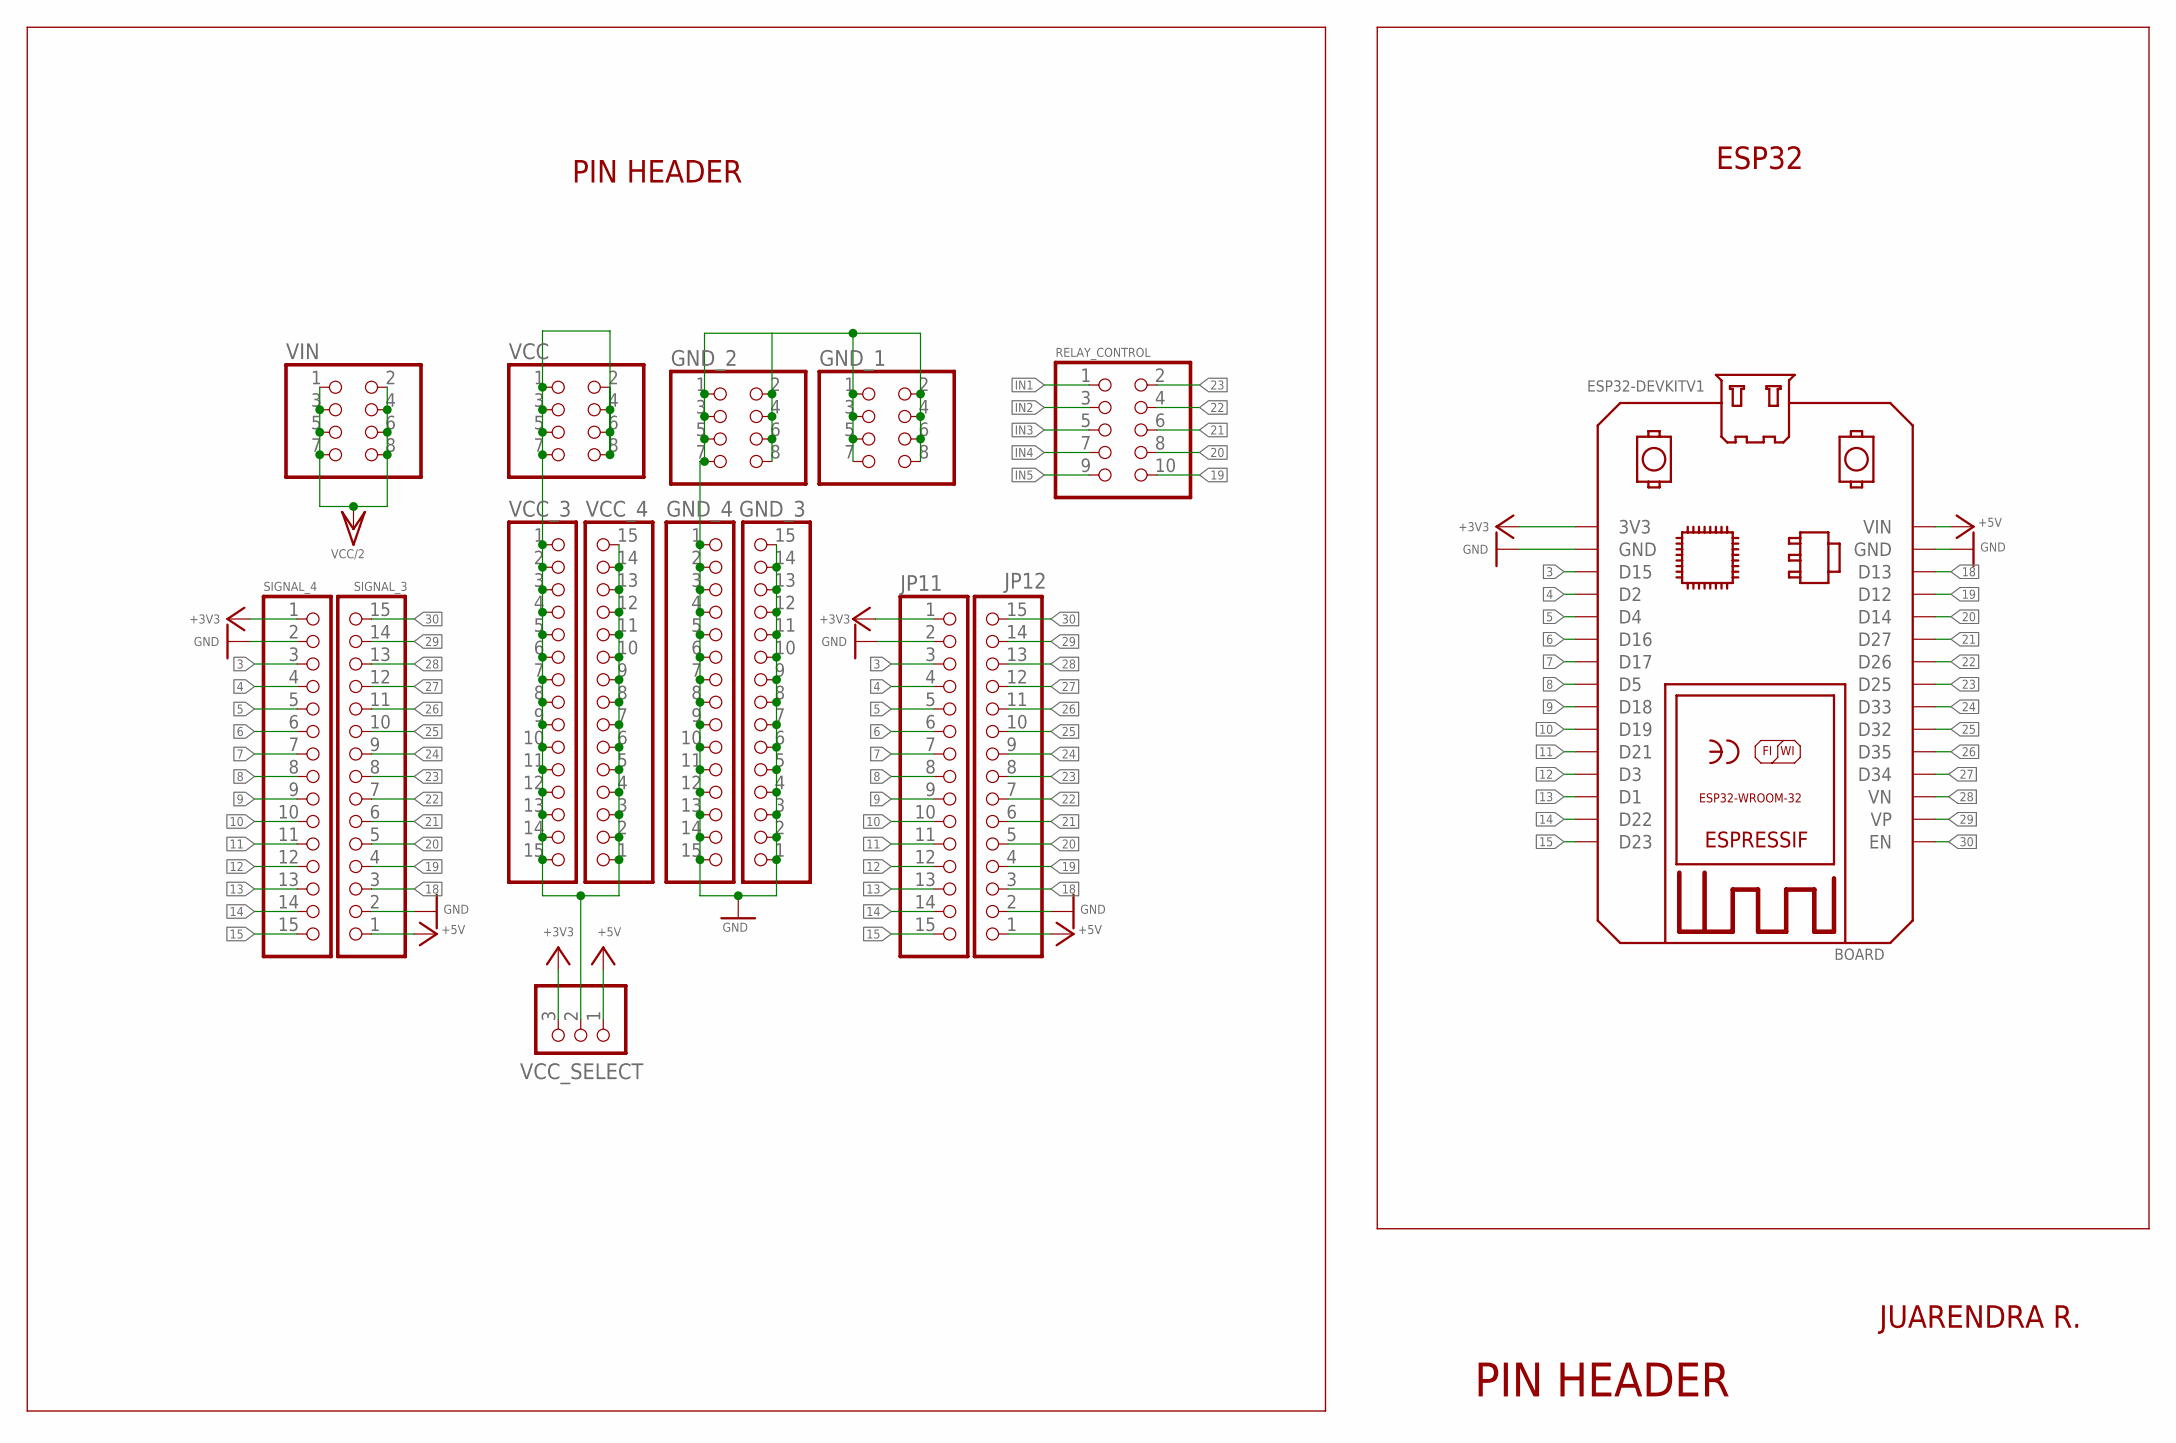
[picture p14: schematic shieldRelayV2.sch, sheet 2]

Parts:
BOARD: ESP32DEVKITV1; ESP32-DEVKITV1
GND_1, GND_2: PINHD-2X4; 2X04
GND_3, GND_4: PINHD-1X15; 1X15
JP11, JP12: PINHD-1X15; 1X15
RELAY_CONTROL: PINHD-2X5; 2X05
SIGNAL_3, SIGNAL_4: PINHD-1X15; 1X15
VCC: PINHD-2X4; 2X04
VCC_3, VCC_4: PINHD-1X15; 1X15
VCC_SELECT: PINHD-1X3; 1X03
VIN: PINHD-2X4; 2X04

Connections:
3: BOARD.D15, JP11.3, SIGNAL_4.3; also elsewhere on the board
4: BOARD.D2, JP11.4, SIGNAL_4.4; also elsewhere on the board
5: BOARD.D4, JP11.5, SIGNAL_4.5; also elsewhere on the board
6: BOARD.D16, JP11.6, SIGNAL_4.6; also elsewhere on the board
7: BOARD.D17, JP11.7, SIGNAL_4.7; also elsewhere on the board
8: BOARD.D5, JP11.8, SIGNAL_4.8; also elsewhere on the board
9: BOARD.D18, JP11.9, SIGNAL_4.9; also elsewhere on the board
10: BOARD.D19, JP11.10, SIGNAL_4.10; also elsewhere on the board
11: BOARD.D21, JP11.11, SIGNAL_4.11; also elsewhere on the board
12: BOARD.D3, JP11.12, SIGNAL_4.12; also elsewhere on the board
13: BOARD.D1, JP11.13, SIGNAL_4.13; also elsewhere on the board
14: BOARD.D22, JP11.14, SIGNAL_4.14; also elsewhere on the board
15: BOARD.D23, JP11.15, SIGNAL_4.15; also elsewhere on the board
18: BOARD.D13, JP12.3, SIGNAL_3.3; also elsewhere on the board
19: BOARD.D12, JP12.4, RELAY_CONTROL.10, SIGNAL_3.4; also elsewhere on the board
20: BOARD.D14, JP12.5, RELAY_CONTROL.8, SIGNAL_3.5; also elsewhere on the board
21: BOARD.D27, JP12.6, RELAY_CONTROL.6, SIGNAL_3.6; also elsewhere on the board
22: BOARD.D26, JP12.7, RELAY_CONTROL.4, SIGNAL_3.7; also elsewhere on the board
23: BOARD.D25, JP12.8, RELAY_CONTROL.2, SIGNAL_3.8; also elsewhere on the board
24: BOARD.D33, JP12.9, SIGNAL_3.9; also elsewhere on the board
25: BOARD.D32, JP12.10, SIGNAL_3.10; also elsewhere on the board
26: BOARD.D35, JP12.11, SIGNAL_3.11; also elsewhere on the board
27: BOARD.D34, JP12.12, SIGNAL_3.12; also elsewhere on the board
28: BOARD.VN, JP12.13, SIGNAL_3.13; also elsewhere on the board
29: BOARD.VP, JP12.14, SIGNAL_3.14; also elsewhere on the board
30: BOARD.EN, JP12.15, SIGNAL_3.15; also elsewhere on the board
+3V3: BOARD.3V3, JP11.1, SIGNAL_4.1, VCC_SELECT.3; also elsewhere on the board
+5V: BOARD.VIN, JP12.1, SIGNAL_3.1, VCC_SELECT.1; also elsewhere on the board
GND: BOARD.GND, BOARD.GND@1 (GND), GND_1.1, GND_1.2, GND_1.3, GND_1.4, GND_1.5, GND_1.6, GND_1.7, GND_1.8, GND_2.1, GND_2.2, GND_2.3, GND_2.4, GND_2.5, GND_2.6, GND_2.7, GND_2.8, GND_3.1, GND_3.2, GND_3.3, GND_3.4, GND_3.5, GND_3.6, GND_3.7, GND_3.8, GND_3.9, GND_3.10, GND_3.11, GND_3.12, GND_3.13, GND_3.14, GND_3.15, GND_4.1, GND_4.2, GND_4.3, GND_4.4, GND_4.5, GND_4.6, GND_4.7, GND_4.8, GND_4.9, GND_4.10, GND_4.11, GND_4.12, GND_4.13, GND_4.14, GND_4.15, JP11.2, JP12.2, SIGNAL_3.2, SIGNAL_4.2; also elsewhere on the board
IN1: RELAY_CONTROL.1; also elsewhere on the board
IN2: RELAY_CONTROL.3; also elsewhere on the board
IN3: RELAY_CONTROL.5; also elsewhere on the board
IN4: RELAY_CONTROL.7; also elsewhere on the board
IN5: RELAY_CONTROL.9; also elsewhere on the board
unnamed: VCC.1, VCC.2, VCC.3, VCC.4, VCC.5, VCC.6, VCC.7, VCC.8, VCC_3.1, VCC_3.2, VCC_3.3, VCC_3.4, VCC_3.5, VCC_3.6, VCC_3.7, VCC_3.8, VCC_3.9, VCC_3.10, VCC_3.11, VCC_3.12, VCC_3.13, VCC_3.14, VCC_3.15, VCC_4.1, VCC_4.2, VCC_4.3, VCC_4.4, VCC_4.5, VCC_4.6, VCC_4.7, VCC_4.8, VCC_4.9, VCC_4.10, VCC_4.11, VCC_4.12, VCC_4.13, VCC_4.14, VCC_4.15, VCC_SELECT.2
VCC/2: VIN.1, VIN.2, VIN.3, VIN.4, VIN.5, VIN.6, VIN.7, VIN.8; also elsewhere on the board

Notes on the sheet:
PIN HEADER
JUARENDRA R.
ESP32

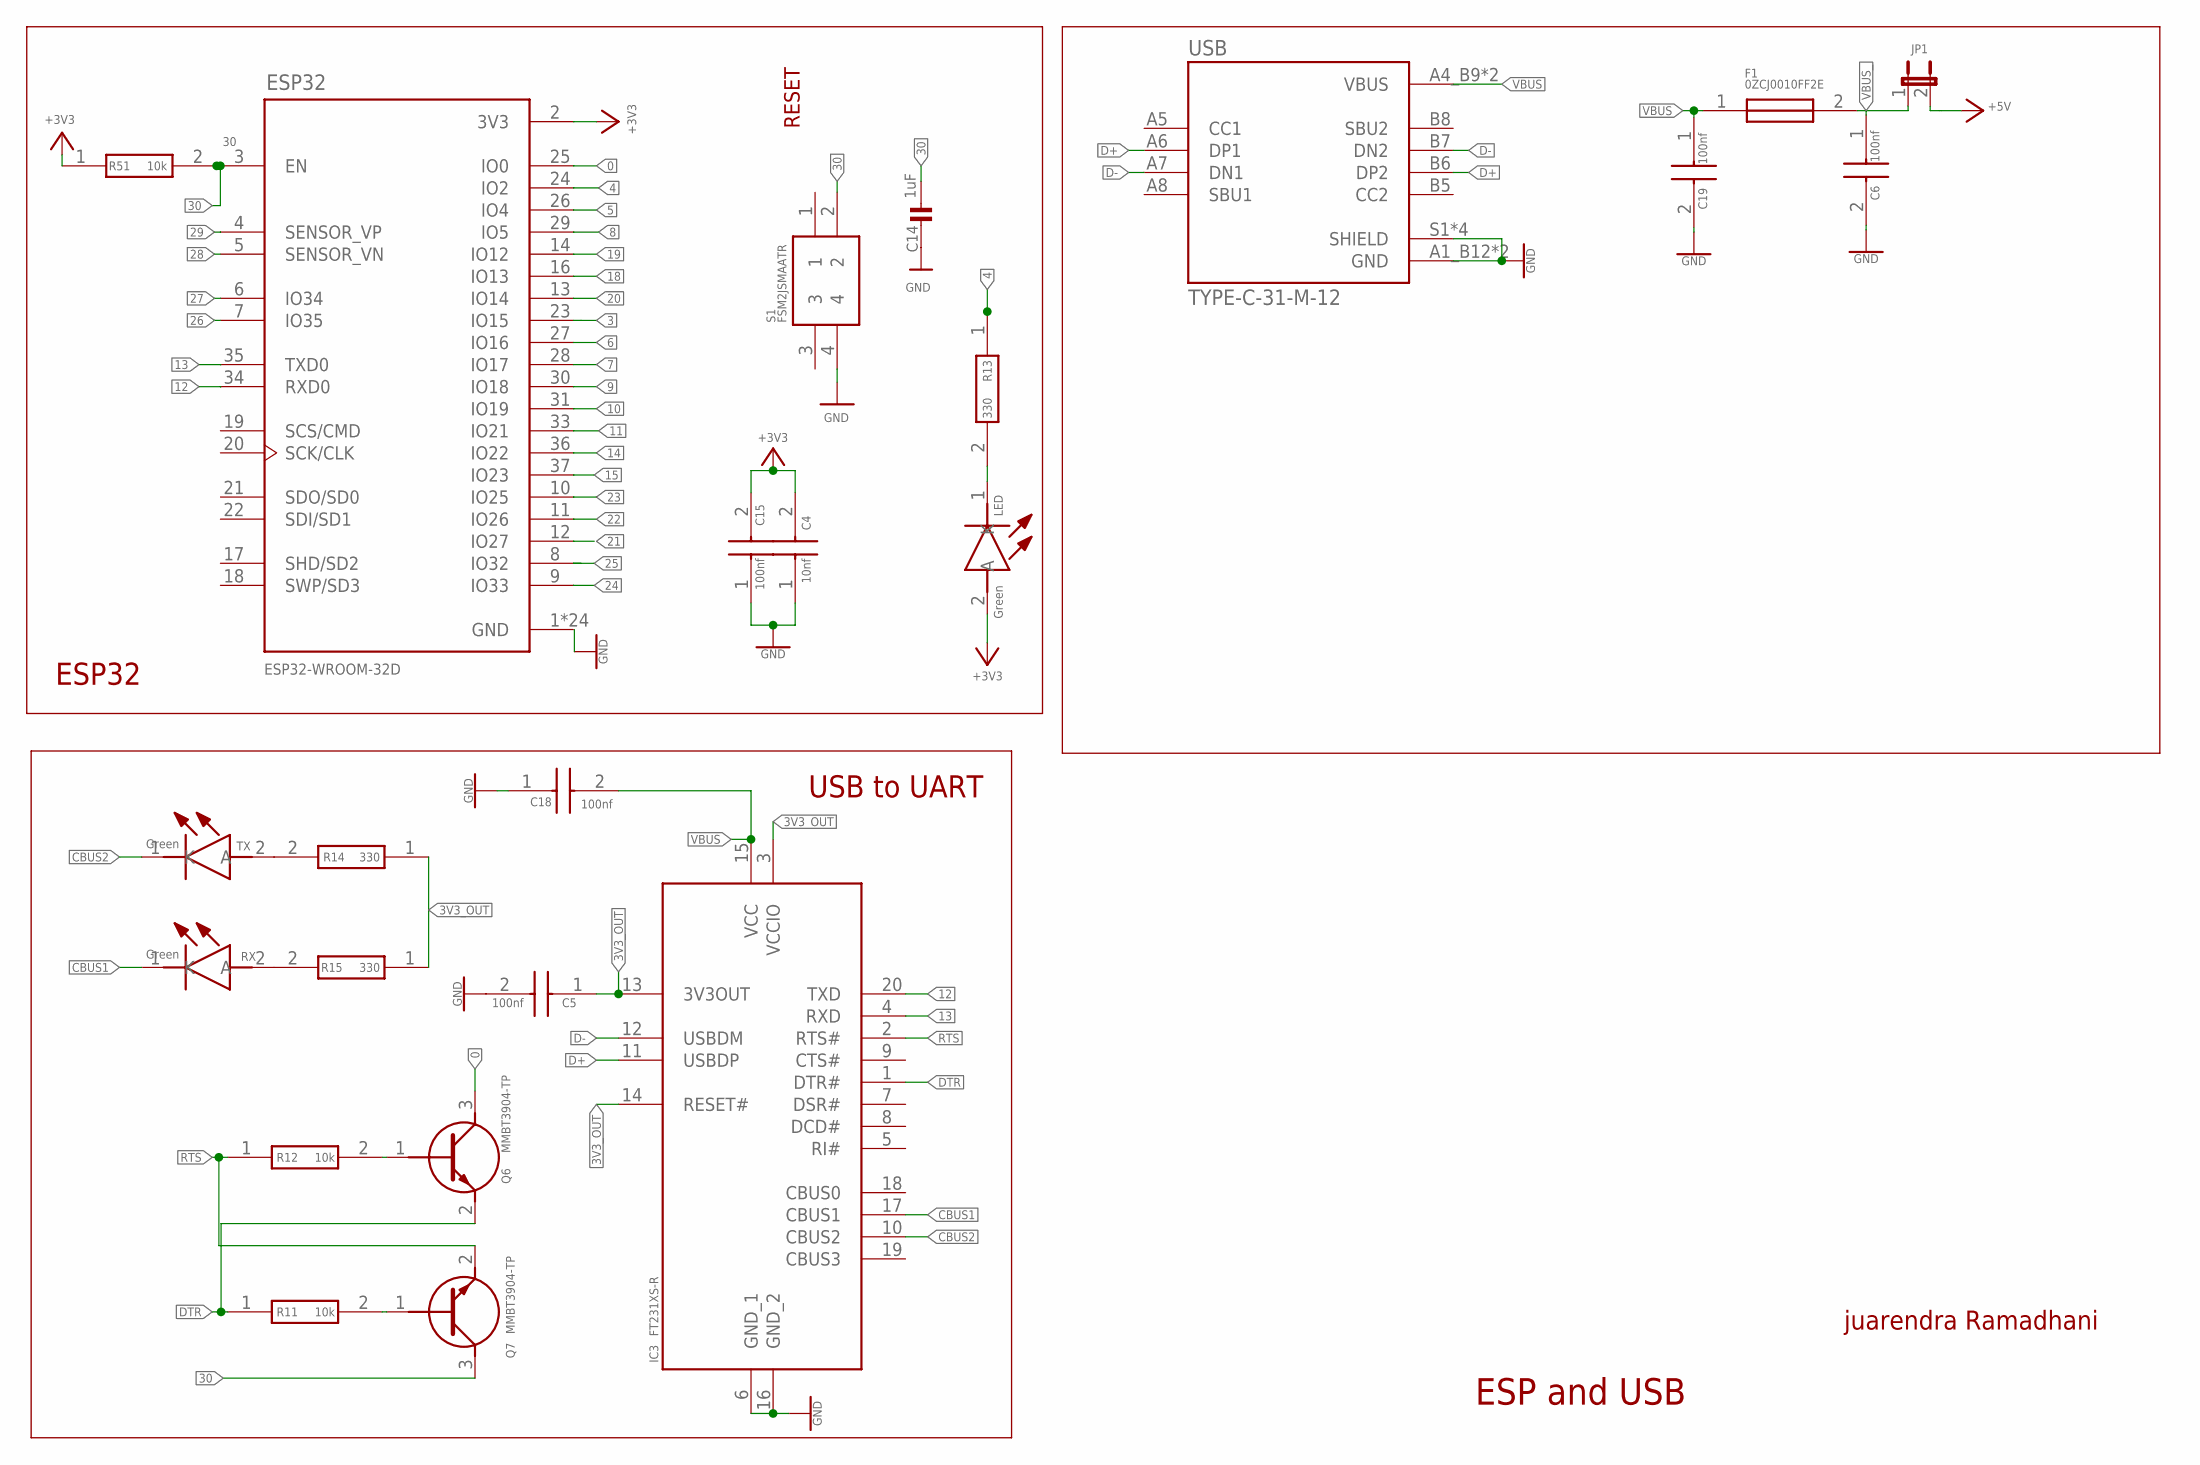
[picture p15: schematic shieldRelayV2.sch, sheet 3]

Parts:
C4: 10nf; CAPC1608X87N
C5, C6, C15, C18, C19: 100nf; CAPC1608X87N
C14: 1uF; 0603
ESP32: ESP32-WROOM-32D; MODULE_ESP32-WROOM-32D
F1: 0ZCJ0010FF2E; FUSC3216X75N
IC3: FT231XS-R; SOP64P599X175-20N
JP1: JP1E; JP1
LED: Green; LEDC2012X80N
Q6, Q7: MMBT3904-TP; SI2305TP
R11, R12, R51: 10k; RESC1608X55N
R13, R14, R15: 330; ERJH3
RX: Green; LEDC2012X80N
S1: FSM2JSMAATR; FSM2J_1
TX: Green; LEDC2012X80N
USB: TYPE-C-31-M-12; HRO_TYPE-C-31-M-12

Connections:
0: ESP32.25 (IO0), Q6.3 (C)
3: ESP32.23 (IO15); also elsewhere on the board
3V3_OUT: C5.1, IC3.3 (VCCIO), IC3.13 (3V3OUT), IC3.14 (RESET#), R14.1, R15.1
4: ESP32.24 (IO2), R13.1; also elsewhere on the board
5: ESP32.26 (IO4); also elsewhere on the board
6: ESP32.27 (IO16); also elsewhere on the board
7: ESP32.28 (IO17); also elsewhere on the board
8: ESP32.29 (IO5); also elsewhere on the board
9: ESP32.30 (IO18); also elsewhere on the board
10: ESP32.31 (IO19); also elsewhere on the board
11: ESP32.33 (IO21); also elsewhere on the board
12: ESP32.34 (RXD0), IC3.20 (TXD); also elsewhere on the board
13: ESP32.35 (TXD0), IC3.4 (RXD); also elsewhere on the board
14: ESP32.36 (IO22); also elsewhere on the board
15: ESP32.37 (IO23); also elsewhere on the board
18: ESP32.16 (IO13); also elsewhere on the board
19: ESP32.14 (IO12); also elsewhere on the board
20: ESP32.13 (IO14); also elsewhere on the board
21: ESP32.12 (IO27); also elsewhere on the board
22: ESP32.11 (IO26); also elsewhere on the board
23: ESP32.10 (IO25); also elsewhere on the board
24: ESP32.9 (IO33); also elsewhere on the board
25: ESP32.8 (IO32); also elsewhere on the board
26: ESP32.7 (IO35); also elsewhere on the board
27: ESP32.6 (IO34); also elsewhere on the board
28: ESP32.5 (SENSOR_VN); also elsewhere on the board
29: ESP32.4 (SENSOR_VP); also elsewhere on the board
30: C14.1, ESP32.3 (EN), Q7.3 (C), R51.2, S1.2; also elsewhere on the board
+3V3: C4.2, C15.2, ESP32.2 (3V3), LED.2 (A), R51.1; also elsewhere on the board
+5V: JP1.2; also elsewhere on the board
CBUS1: IC3.17 (CBUS1), RX.1 (K)
CBUS2: IC3.10 (CBUS2), TX.1 (K)
D+: IC3.11 (USBDP), USB.A6 (DP1), USB.B6 (DP2)
D-: IC3.12 (USBDM), USB.A7 (DN1), USB.B7 (DN2)
DTR: IC3.1 (DTR#), Q6.2 (E), R11.1
GND: C4.1, C5.2, C6.2, C14.2, C15.1, C18.1, C19.2, ESP32.1 (GND), ESP32.15 (GND), ESP32.38 (GND), ESP32.39_1 (GND), ESP32.39_2 (GND), ESP32.39_3 (GND), ESP32.39_4 (GND), ESP32.39_5 (GND), ESP32.39_6 (GND), ESP32.39_7 (GND), ESP32.39_8 (GND), ESP32.39_9 (GND), ESP32.39_10 (GND), ESP32.39_11 (GND), ESP32.39_12 (GND), ESP32.39_13 (GND), ESP32.39_14 (GND), ESP32.39_15 (GND), ESP32.39_16 (GND), ESP32.39_17 (GND), ESP32.39_18 (GND), ESP32.39_19 (GND), ESP32.39_20 (GND), ESP32.39_21 (GND), IC3.6 (GND_1), IC3.16 (GND_2), S1.4, USB.A1_B12 (GND), USB.B1_A12 (GND), USB.S1 (SHIELD), USB.S2 (SHIELD), USB.S3 (SHIELD), USB.S4 (SHIELD); also elsewhere on the board
unnamed: Q7.1 (B), R11.2
unnamed: Q6.1 (B), R12.2
unnamed: R15.2, RX.2 (A)
unnamed: R14.2, TX.2 (A)
unnamed: LED.1 (K), R13.2
RTS: IC3.2 (RTS#), Q7.2 (E), R12.1
VBUS: C18.2, C19.1, F1.1, IC3.15 (VCC), USB.A4_B9 (VBUS), USB.B4_A9 (VBUS)
VBUS_: C6.1, F1.2, JP1.1

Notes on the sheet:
RESET
ESP32
USB to UART
ESP and USB
juarendra Ramadhani

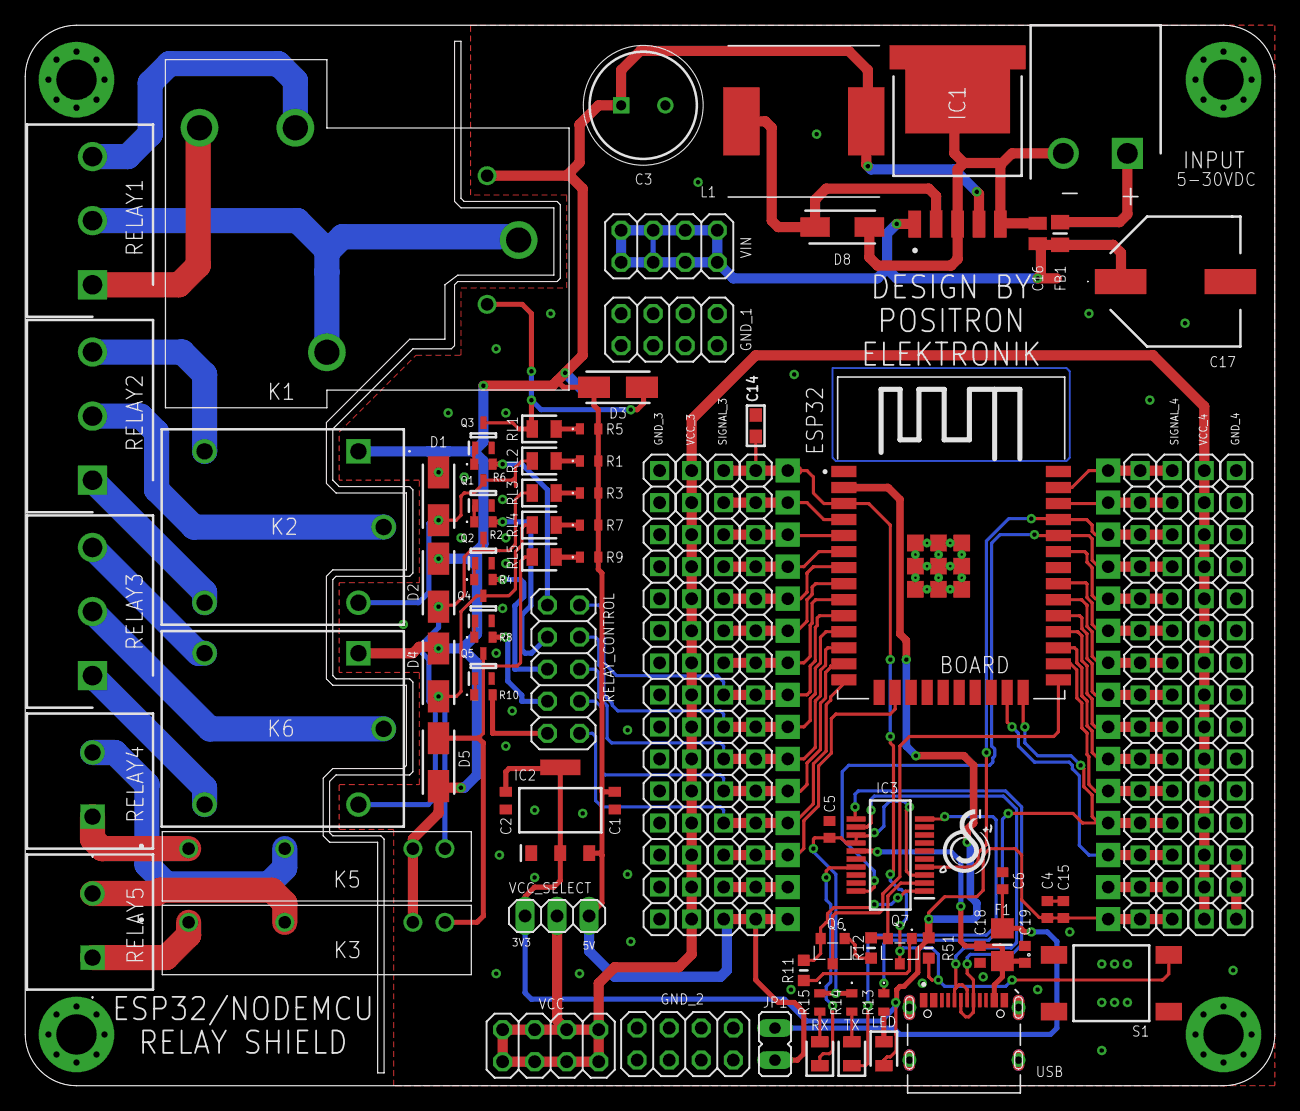
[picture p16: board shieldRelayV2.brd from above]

Board: 2 copper layers, 99.1 x 84.1 mm, 89 parts (1 on the bottom side), 81 nets.

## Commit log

2024-06-15 FEAT: update sch, board, gerber adn bom for esp embedded to pcb
    [BOM_shieldRelay.csv, shieldRelayV2.brd, shieldRelayV2.csv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]
2024-06-16 FIX: fix minor pcb
    [shieldRelayV2.brd]
2024-06-18 FIX: fix gnd pin on ic 1117 that no connected
    [shieldRelayV2.brd, shieldRelayV2.sch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]
2024-06-18 FIX: fix led pin io2 ond katoda connected to 3v3 otherwise gns
    [shieldRelayV2.brd, shieldRelayV2.sch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]
2024-07-19 FIX: fix reverse transistor relay
    [shieldRelayV2.brd, shieldRelayV2.sch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]

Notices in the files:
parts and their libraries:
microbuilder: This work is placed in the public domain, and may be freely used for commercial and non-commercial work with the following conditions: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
